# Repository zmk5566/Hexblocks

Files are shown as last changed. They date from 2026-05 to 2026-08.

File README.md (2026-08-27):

<h1 align="center">HexBlocks</h1>

<p align="center">
  <em>Open-Source Prototyping of Reconfigurable Physical Interfaces with Semantic Continuity</em>
</p>

<p align="center">
  <a href="https://zmk5566.github.io/Hexblocks/">Walkthrough</a>
</p>

<p align="center">
  HexBlocks modules arranged for a live prototype
</p>

HexBlocks is an open-source software-hardware framework for rapid, on-the-fly prototyping of reconfigurable physical interfaces. It combines magnetic sensor/actuator modules, a battery-powered hub, a browser authoring UI, and a live schema in one workspace.

The core design goal is semantic continuity: physical modules, authoring references, and runtime targets stay bound to stable UID-keyed entities as the assembly changes. The reference implementation supports hub-resident Event-Condition-Action execution for standalone prototypes and sensor-stream integration through a Python bridge for browser and OSC workflows.

## Interface

<p align="center">
  HexBlocks interface
</p>

## Links

- Video walkthrough: <https://zmk5566.github.io/Hexblocks/>
- Schematics: [`schematics/`](schematics/) (KiCad project `schematics.kicad_pro`)
- Enclosures: [`openscad-model/`](openscad-model/) (OpenSCAD sources + STL)
- Hardware sources: [`hardware/`](hardware/) (firmware + PCB)
- Firmware topology runtime: [`hardware/docs/topology-runtime.md`](hardware/docs/topology-runtime.md)

## Repo layout

```
hardware/             ESP32-C3 firmware (hub + 7 module types) and PCB
  firmware/hub/       six-face wired Hub — CAN master, BLE/USB, ECA
  firmware/wifi_hub/  same shared Hub core plus Wi-Fi/OSC fallback
  firmware/motor_hub/ one-face BLE/USB hub with a built-in dual-motor actuator
  firmware/module_*/  per-module sketches (imu, led, vibration, motor,
                      amplifier, light_resistor, resistor)
  firmware/lib/       shared C++ libraries: WearBlocksCAN, *Protocol,
                      *Descriptor, *Module, *ECA (bytecode interpreter),
                      *Transport policy and optional *Wireless runtime
  pcb/                board files
schematics/           KiCad project (board + schematic)
openscad-model/       hex enclosure SCAD sources + exported STL
frontend/
  bridge/             Python bridge runtime: serial_bridge.py (WS + HTTP),
                      OSC forwarding + correlated control ingress,
                      wb_protocol.py, wb_eca.py, transport.py (USB-CDC + BLE)
  js/                 ES modules: ws-client, eca-encoder/decoder,
                      llm-catalog, recommendation-plan, demo-programs
  js/components/      Lit UI: wb-app, wb-block-canvas, wb-sim-stage (Three.js), wb-llm-panel,
                      wb-sensor-panel, wb-eca-inspector, wb-status-bar,
                      wb-devices-panel, wb-debug-console
  tools/              frontend smoke/debug utilities
  index.html          static entry point, served by the bridge
```

## Quickstart - Simulator

Use simulator mode first if you do not have hardware attached.

1. **Install bridge dependencies.**

   ```bash
   cd frontend/bridge
   python -m venv .venv
   source .venv/bin/activate
   pip install -r requirements.txt
   ```

2. **Run the bridge simulator.**

   ```bash
   python serial_bridge.py --sim --sim-demo
   ```

3. **Open the UI.** Browse to `http://localhost:3000`.

The bridge serves the static frontend on port 3000 and broadcasts live events
on `ws://localhost:8765`. The simulator creates a demo topology for testing
Blockly upload, ECA execution, actuator state replay, and OSC forwarding
without flashing a hub.

Run the core bridge checks:

```bash
cd frontend/bridge
python serial_bridge.py --selftest
python -m pytest test_wb_eca.py test_osc_bridge.py test_llm_bridge.py
```

## Quickstart - Hardware Hub-Resident ECA

The hub evaluates rules locally. A companion computer is only needed to author or inspect the program.

1. **Flash the hub.** Connect the hub board over USB-C. The default
   `hardware/firmware/hub` target is the deterministic wired build: CAN module
   bus plus USB/BLE companion link, with no Wi-Fi SoftAP or OSC listener.
   Compile it for ESP32-C3 with `arduino-cli`:

   ```bash
   # Install the core once
   arduino-cli core install esp32:esp32

   # Compile and upload (replace /dev/cu.usbmodem* with your port)
   arduino-cli compile --fqbn esp32:esp32:esp32c3 \
     --libraries hardware/firmware/lib hardware/firmware/hub
   arduino-cli upload --fqbn esp32:esp32:esp32c3 \
     -p /dev/cu.usbmodem* hardware/firmware/hub
   ```

   To enable module-to-Hub Wi-Fi/OSC fallback, compile and upload
   `hardware/firmware/wifi_hub` instead. Both targets share the same Hub and
   registry implementation; `wifi_hub` only selects the wireless adapter.

   ```bash
   arduino-cli compile --fqbn esp32:esp32:esp32c3 \
     --libraries hardware/firmware/lib hardware/firmware/wifi_hub
   arduino-cli upload --fqbn esp32:esp32:esp32c3 \
     -p /dev/cu.usbmodem* hardware/firmware/wifi_hub
   ```

   For the standalone ESP32-C3FH4 + DRV8410 board, compile and upload
   `hardware/firmware/motor_hub` instead. It exposes the same BLE/USB hub
   protocol, uses GPIO5 as its single external Face 1, and advertises its
   onboard M1/M2 pair as `Built-in Dual Motor` without consuming a CAN slot.

2. **Flash each module.** Same flow, one sketch per module type. Example for the IMU module:

   ```bash
   arduino-cli compile --fqbn esp32:esp32:esp32c3 \
     --libraries hardware/firmware/lib hardware/firmware/module_imu
   arduino-cli upload --fqbn esp32:esp32:esp32c3 \
     -p /dev/cu.usbmodem* hardware/firmware/module_imu
   ```

   Repeat for `module_led`, `module_vibration`, `module_motor`, `module_amplifier`, `module_light_resistor`, `module_resistor`.

3. **Power up.** Snap modules onto the hub. The hub enumerates them over CAN, allocates slots, and (if a program is in NVS) starts evaluating immediately. No companion computer required.

4. **Author or replace the program (optional).** Run the bridge (see Mode B), open the browser UI, write rules in the Blockly canvas or via the LLM panel, and click upload. The encoded bytecode is sent as `$P <base64>` over the active transport, persisted in NVS, and runs on every boot until cleared with `$PC` (clear) or `$PE` (erase NVS).

### ECA v4 timing model

ECA timing is cooperative: the Hub never sleeps or busy-waits while a rule is delayed. `hold_ms` and `cooldown_ms` belong to the rule; each action independently has `delay_ms`, `duration_ms`, and one of three modes:

- `TRIGGER`: starts once per rule episode. A delayed trigger remains scheduled after a one-tick event is consumed.
- `WHILE_TRUE`: stays active only while the rule remains true.
- `STREAM`: refreshes live sensor/VC/variable parameters at `update_interval_ms` (minimum 20 ms).

Transient event channels such as shake, free-fall, and HR spike must use rule `hold_ms = 0`; use action `delay_ms` when the response should happen later.

LED, vibration, and audio outputs use ownership tokens so an older duration timer cannot stop a newer effect on the same module. Stop, clear, and program replacement emit a safe output-specific stop. The output modules also enforce duration locally; `STREAM` commands renew a short lease, so a lost Hub/CAN connection expires the output without waiting for a final STOP frame.

ECA v4 is a wire-format change. Reflash the Hub plus `module_led`, `module_vibration`, and `module_amplifier`, then upload the workspace again; the Hub intentionally uses a new `prog_v4` NVS key rather than interpreting stored v3 bytes.

## Quickstart - Sensor Stream + Browser

Same hardware setup as Mode A. The hub keeps any uploaded program running; the bridge subscribes to the same `$S/$D/$H/$T` stream and forwards it to the browser. Clearing the program (`$PC`) gives a pure stream-only configuration.

1. **Install the bridge dependencies.**

   ```bash
   cd frontend/bridge
   pip install -r requirements.txt   # websockets, pyserial, requests, bleak
   ```

2. **Run the bridge.** The bridge serves the static frontend on `http://localhost:3000` and pushes events on `ws://localhost:8765`.

   ```bash
   # USB-CDC (auto-detect or pass a port)
   python serial_bridge.py /dev/cu.usbmodem*

   # First run: start idle, then choose USB serial or BLE in the Connections panel.
   python serial_bridge.py --idle

   # BLE direct reconnect, after a device address is known:
   python serial_bridge.py --ble <BLE_ADDRESS>

   # No hardware? Headless simulator with three demo programs:
   python serial_bridge.py --sim --sim-demo
   ```

3. **Open the UI.** Browse to `http://localhost:3000`. Sparklines appear in `wb-sensor-panel`; raw bridge traffic in `wb-debug-console`; the program currently on the hub in `wb-eca-inspector`.

4. **Optional: LLM authoring.** Set `DEEPSEEK_API_KEY` in `frontend/bridge/.env` so the bridge's `/api/chat` proxy can reach the model. The chat panel translates utterances into `<workspace_update>` envelopes that the canvas validates against the live module schema before letting you accept.

5. **Optional: bidirectional OSC.** Open the OSC panel from the status bar,
   add a loopback forwarding target, and use auto-populate to seed one address
   per live sensor channel. The bridge also listens on `127.0.0.1:7001` for
   `/hex/control/<uid>/actuator` and replies with correlated
   `ack`/`nack`/`state` messages. Non-loopback OSC in either direction requires
   launching the bridge with `--osc-allow-remote`.

## Build Instructions

### Firmware

No `platformio.ini` is committed — the canonical build path is `arduino-cli` against the per-sketch directories under `hardware/firmware/`. Shared libraries live in `hardware/firmware/lib/` and must be passed via `--libraries` (see commands above). Target board: `esp32:esp32:esp32c3` (ESP32-C3-MINI-1). The hub additionally requires NimBLE-Arduino; install it once with `arduino-cli lib install "NimBLE-Arduino"`.

PlatformIO users can build the same sketches by adding each `module_*`, `hub`,
`wifi_hub`, and `motor_hub` directory as a PlatformIO environment with
`framework = arduino` and `board = esp32-c3-devkitm-1`; no project file is
provided.

### Bridge

```bash
cd frontend/bridge
python -m venv .venv && source .venv/bin/activate
pip install -r requirements.txt
python serial_bridge.py --selftest    # parser + ECA round-trip checks
```

Tested with CPython 3.11. No `pyproject.toml`; the bridge is a small set of scripts driven by `requirements.txt`.

### Frontend

The frontend is plain ES modules. There is no bundler and no build step.
`serial_bridge.py` serves `frontend/index.html` and `frontend/js/` directly
over HTTP on port 3000. Open `http://localhost:3000` in a Chromium-based
browser. The Connections panel is mediated by the Python bridge, so USB serial
selection and BLE pairing also work in Firefox.

## License

- Code: MIT. See [`LICENSE`](LICENSE).
- Hardware design files and enclosure models: CC BY 4.0. See
  [`LICENSE-hardware`](LICENSE-hardware).

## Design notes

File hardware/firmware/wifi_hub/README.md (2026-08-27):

# WearBlocks Wi-Fi Hub

This is the six-face Hub build with the optional Wi-Fi/OSC module transport.
It shares the complete runtime and `ModuleRegistry` implementation with
`../hub`; this directory only selects the wireless adapter at compile time.

Choose one six-face Hub target:

| Target | Runtime links | Wi-Fi SoftAP / OSC |
|---|---|---|
| `hardware/firmware/hub` | CAN + USB/BLE | No |
| `hardware/firmware/wifi_hub` | CAN + USB/BLE + Wi-Fi | Yes |

Compile this variant with:

```bash
arduino-cli compile --fqbn esp32:esp32:esp32c3 \
  --libraries hardware/firmware/lib hardware/firmware/wifi_hub
```

The Wi-Fi Hub provisions supported modules over CAN, runs a WPA2 SoftAP, and
accepts UID-keyed OSC-over-UDP samples. ECA execution remains on the Hub. See
[`hardware/docs/wifi-osc-fallback.md`](../../docs/wifi-osc-fallback.md) for the
transport modes and wire protocol.

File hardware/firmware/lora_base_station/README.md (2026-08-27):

# WearBlocks LoRa Base Station

Firmware target: ESP32-S3 + SX1262.

Install Arduino libraries before compiling:

- RadioLib
- ArduinoJson

Edit these constants at the top of `lora_base_station.ino` before flashing:

- `WIFI_SSID`
- `WIFI_PASS`
- `HTTP_ENDPOINT`
- `HTTP_BEARER_TOKEN`
- SX1262 pins
- LoRa frequency/power parameters

Runtime behavior:

- Receives `WBLR` batch frames from LoRa logger modules.
- Uploads each new batch with `HTTP POST`.
- Sends a LoRa ACK only after the HTTP API returns 2xx.
- Re-ACKs duplicate `(node_uid, boot_id, sequence)` batches from a short RAM cache.

RF defaults are CN470-like placeholders. Confirm the final frequency, power,
antenna, duty-cycle assumptions, and SRRC requirements before field use.

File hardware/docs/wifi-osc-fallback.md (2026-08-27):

# Wi-Fi / OSC Fallback Runtime

Status: end-to-end sensor, actuator, topic, ACK/retry, and duplicate-suppression
runtime for the explicit `wifi_hub` variant.

This runtime belongs to the explicit `hardware/firmware/wifi_hub` build. The
default `hardware/firmware/hub` build shares the same CAN/BLE/USB/ECA core but
does not include Wi-Fi, create a SoftAP, or listen for OSC/UDP packets.

```bash
arduino-cli compile --fqbn esp32:esp32:esp32c3 \
  --libraries hardware/firmware/lib hardware/firmware/wifi_hub
```

The reference system still treats CAN as the deterministic local module bus,
but each module can carry a transport policy. The hub can run a WPA2 SoftAP and
accept OSC-over-UDP packets from Wi-Fi modules. ECA execution remains on the
hub; CAN and Wi-Fi sensor samples update the same UID-keyed ECA cache.

## Transport modes

Configured per module:

| Mode | Behavior |
|---|---|
| `can_only` | Use CAN only. Ignore Wi-Fi sensor samples. |
| `wifi_only` | Use Wi-Fi for runtime data even if CAN is physically present. |
| `can_primary_wifi_fallback` | Default. Use CAN while healthy; switch to Wi-Fi after CAN detach/fail. |
| `wifi_primary_can_fallback` | Prefer Wi-Fi when the endpoint is known; use CAN if Wi-Fi is unavailable. |
| `dual_send_debug` | Send actuator/topic commands over both links and accept both sensor paths for debugging. |

Hub commands:

```text
$W,INFO
$W,CONFIG ALL <mode>
$W,CONFIG <uidHex> <mode>
```

`$W,INFO` emits the SoftAP SSID, AP IP, UDP port, AP password, and pairing
token. The first module provisioning and recovery path is still CAN: attach the
module, use the hub command path to set the module configuration, then let the
module persist it in NVS.

## CAN provisioning

Wi-Fi profile data is sent over CAN with a dedicated system config path, not
the actuator config path:

```text
WB_MSG_SYS_CONFIG      0x090
WB_MSG_SYS_CONFIG_ACK  0x091
```

The hub sends a chunked binary profile to the assigned module slot after ACK
and whenever `$W,CONFIG` changes a module's transport mode. The profile
contains `hubId`, `ssid`, `pass`, `token`, `udpPort`, `transportMode`, an
enabled flag, and a FNV32 checksum. Modules save the profile in NVS and can
reconnect to the same hub SoftAP without CAN on later boots.

The hub SoftAP SSID is unique by default:

```text
HEX-<hubShortId>
```

The AP password and OSC token are generated once and persisted in hub NVS.

## Hub wire output

The hub adds link-state lines to the existing `$` protocol:

```text
$W,<uid>,<activeLink>,<transportMode>,<topologyState>,<ip>,<port>
$WIFI,AP,<ssid>,<ip>,<port>
$WIFI,PASS,<password>
$WIFI,TOKEN,<token>
```

Wireless-only modules use `REMOTE,0` as their parent label in `$H` and `$T`
rows. The bridge maps that to `parent_remote=true` and the UI renders the module
as remote/unplaced rather than attached to a hub face.

## OSC messages

All OSC messages use typed arguments. Runtime samples are latest-value wins;
configuration and actions carry IDs so the receiver can ACK, NACK, retry, and
deduplicate.

Module to hub:

```text
/wb/module/hello       s i s i s   uid, fwHash, transportMode, seq, token
/wb/module/heartbeat   s i s s     uid, seq, linkState, token
/wb/sensor             s i f i s   uid, channel, value, seq, token
/wb/descriptor/blob    s i i b s   uid, fwHash, seq, serializedDescriptor, token
/wb/ack                s i s       uid, msgId, status
/wb/nack               s i s       uid, msgId, reason
```

Hub to module:

```text
/wb/descriptor/request s i i s     uid, fwHash, msgId, token
/wb/action             s i i i b s uid, cmd, msgId, paramLen, params, token
/wb/topic              s i i i s   uid, channel, enable, msgId, token
```

Broadcast is intentionally reserved for discovery and low-frequency status.
Runtime sensor and actuator/control messages should be unicast between a module
and the hub.

For actions and topic changes, the Hub keeps a fixed pending table and retries
after 250 ms, up to three sends. Modules remember the most recent action and
topic message IDs: a retry is ACKed again but its callback is not executed a
second time. ECA `STREAM` action updates and repeated desired topic state are
coalesced while an ACK is outstanding, preventing a slow Wi-Fi link from
turning into an unbounded queue.

The companion-visible correlated wire lines are:

```text
$AO <requestId> <uid> <cmd> [wire params...]       host control request
$AS,<uid>,<cmd>,<paramLen>,<hex>[,<requestId>]     routed state echo
$WA,<uid>,<msgId>,<detail>[,<requestId>]           module ACK
$WN,<uid>,<msgId>,<reason>[,<requestId>]           module NACK/timeout
```

The standard wired Hub understands `$AO` and emits `$AS` too, but never starts
Wi-Fi. This keeps `hub` deterministic while `wifi_hub` owns the wireless
fallback policy.

## Module coverage

- `module_resistor`, `module_light_resistor`, and `module_imu` route sensor
  samples through `WBWirelessModule`.
- `module_led`, `module_vibration`, `module_amplifier`, and `module_motor`
  receive Wi-Fi actuator commands through the same wrapper.
- CAN remains active according to each module's transport policy; the wrapper
  does not fork the application-level actuator implementation.

## Current limitations

- Descriptor transfer is implemented as a single OSC blob. If descriptor or
  config payloads grow beyond one safe UDP datagram, promote this to chunked
  `seq/index/total/crc` transfer.
- ESP32-C3 can run CAN, Wi-Fi, and BLE, but Wi-Fi and BLE share the 2.4 GHz RF.
  During Wi-Fi fallback, BLE should stay on low-frequency status/config traffic.

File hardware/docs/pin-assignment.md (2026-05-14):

# WearBlocks Pin Assignment

> **2026-04 update — digital-presence PosID**
> Hub is now **ESP32-C3-MINI-1** (not S3). PosID uses **digital presence**
> (internal pull-up on hub + POS_ID tied to GND on module's docking face),
> not ADC + resistor network. See `posid-topology.md` for historical notes
> and the current scheme.

## Hub: ESP32-C3-MINI-1

| GPIO | Function | Notes |
|---|---|---|
| GPIO6 | TWAI_TX (CAN TX) | To SN65HVD230 TXD. Repurposes JTAG MTCK. |
| GPIO7 | TWAI_RX (CAN RX) | From SN65HVD230 RXD. Repurposes JTAG MTDO. |
| GPIO0 | Face 1 presence | digital INPUT_PULLUP. **Boot strap — caution**: module must not short this to GND at power-up. |
| GPIO2 | Face 2 presence | digital INPUT_PULLUP. **Boot strap — caution** as above. |
| GPIO3 | Face 3 presence | digital INPUT_PULLUP. Clean ADC1_CH3 line per user test. |
| GPIO4 | Face 4 presence | digital INPUT_PULLUP. Clean. |
| GPIO8 | Face 5 presence | digital INPUT_PULLUP. **Boot strap — caution.** Sometimes wired to onboard LED on dev boards — test first. |
| GPIO10 | Face 6 presence | digital INPUT_PULLUP. |
| GPIO9 | Status LED (optional) | Boot button on most dev boards; OK to drive as output after boot. |
| GPIO18 | USB D- | USB-OTG if using native USB as serial |
| GPIO19 | USB D+ | |
| GPIO20/21 | UART0 RX/TX | For flashing + serial console via USB-UART |

**ADC note**: ESP32-C3 only has 5 usable ADC1 pins (GPIO 0–4) and ADC2 (GPIO 5) is unsupported by the Arduino-ESP32 core. For the face count to reach 6 on C3, we switched PosID from analog to digital; this also sidesteps dev-board ADC pin contamination and calibration.

**Strap pin caveat**: GPIO 0/2/8/9 are boot-mode strapping pins. A module plugged into its corresponding face at power-up will short the strap pin to GND, which can force the MCU into download mode. Boot procedure in firmware:
- Power hub on with all faces empty, wait for `[WAIT] Listening for module HELLO`
- Then plug modules in

Once the bootloader has handed off, these pins are free to read LOW. A future PCB respin should avoid strap pins for face presence; for breadboard prototypes the workaround above is acceptable.

## Module: ESP32-C3-MINI-1

| GPIO | Function | Notes |
|---|---|---|
| GPIO0 | TWAI_TX (CAN TX) | To SN65HVD230 TXD. Strap pin — must not boot low; default TWAI idles high. |
| GPIO1 | TWAI_RX (CAN RX) | From SN65HVD230 RXD |
| GPIO3 | I2C SDA | For MPU6050, MAX30102, BME280 |
| GPIO4 | I2C SCL | |
| GPIO2 | Child-presence face A (down-half stack detect) | INPUT_PULLUP. Strap pin caveat applies when a child module is stacked at boot. |
| GPIO5 | Child-presence face B (down-half stack detect) | INPUT_PULLUP. ADC2 unreliable but digital is fine. |
| GPIO10 | Child-presence face C (down-half stack detect) | INPUT_PULLUP. |
| GPIO8 | Status LED | Module state indicator |
| GPIO9 | Boot button / reserved | |

**PosID behaviour**:
- Module's docking face has its POS_ID pin **hard-tied to GND on the PCB** (or equivalently to POS_GND pin of the connector — they're both ground).
- Module does not need to read its own POS_ID; `MY_FACE` is a compile-time constant baked in firmware per PCB variant.
- Module's three "down-half" faces have POS_ID routed to INPUT_PULLUP GPIOs (above), so the module detects when someone stacks onto it, and broadcasts `WB_MSG_CHILD_EVENT` on CAN.

## SN65HVD230 CAN Transceiver Wiring

| Pin | Connection |
|-----|---|
| TXD | ESP32 TWAI_TX GPIO |
| RXD | ESP32 TWAI_RX GPIO |
| CANH | Bus CAN-H (to pogo pin) |
| CANL | Bus CAN-L (to pogo pin) |
| VCC | 3.3V |
| GND | GND |
| Rs | GND (slope control = high speed) |
| Vref | NC (unused) |

**Bus termination:** 120Ω between CAN-H and CAN-L on the hub only.

## 6-Pin Hex Face Connector (unchanged physically; POS_ID role changed)

| Pin # | Signal | Direction | Notes |
|---|---|---|---|
| 1 | CAN-H | Bidirectional | Shared bus |
| 2 | CAN-L | Bidirectional | Shared bus |
| 3 | VCC | Power out (hub / host module) | 3.3V |
| 4 | GND | Common ground | |
| 5 | POS_ID | **Digital low = dock present** | On child side: tied to GND. On host side: GPIO with internal pull-up. |
| 6 | POS_GND | GND reference | Dedicated ground alongside POS_ID for clean digital reference |

## PosID detection logic

```
Host side (hub or parent module):
    pinMode(FACE_PIN_N, INPUT_PULLUP);
    bool occupied = (digitalRead(FACE_PIN_N) == LOW);

Child side (docking face):
    POS_ID pin on the PCB is a solder trace to GND. No MCU code involved.

Identity:
    Module sends CAN HELLO with MY_FACE (compile-time constant encoded in firmware).
    Host cross-checks: "I saw my face N just become occupied AND this HELLO just arrived → they correlate."

Stack:
    Each host module has 3 child-presence GPIOs (down-half faces only).
    When any goes LOW, module sends WB_MSG_CHILD_EVENT_BASE+mySlot on CAN.
    Hub consumes these events to maintain the parent-child tree.
```

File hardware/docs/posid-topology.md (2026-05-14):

# PosID Wiring — Topology B (Symmetric)

This is the canonical wiring spec for the 6-face PosID circuit on every WearBlocks hex (hub or module).  
It's the **only** topology (out of the three we considered) that supports **both** connection modes:

- **A. Hub ↔ Module** — module plugs into any of the hub's 6 faces.
- **B. Module ↔ Module stack** — one module's face docks to another module's face.

Rationale: since a module can play either role (host or guest in a stack), every face on every hex needs to be electrically self-sufficient. If one side relies on the neighbor to provide the pull-up (or pull-down), the circuit collapses whenever that neighbor happens not to have it — exactly what breaks module-on-module stacking.

## Per-face schematic

Every hex face (on hub **and** on every module) is wired identically:

```
                VCC  (3.3V rail)
                 │
                 │
                ┌┴┐
                │ │   R_face_N     ← unique per face position N = 1..6
                │ │   (1k / 2.2k / 3.3k / 4.7k / 6.8k / 10k)
                └┬┘
                 │
                 ├─────o POS_ID   ─── pogo pin ───►  to neighbor's POS_ID
                 │
                 ├─────o ADC_N    (only connected on sides that read this face;
                 │                 hub reads all 6; proto-module reads its 1 active face)
                 │
                ┌┴┐
                │ │   10 kΩ       (pull-down, same value on every face)
                │ │
                └┬┘
                 │
                 │
                GND
                 │
                 └─────o POS_GND  ─── pogo pin ───►  common ground reference
```

Per face you need **exactly 2 resistors**:
- `R_face_N` (pull-up to VCC) — identifies the face position
- `10 kΩ` (pull-down to GND) — shared reference

## R_face values by position

| Face N | R_face_N | V_idle (no neighbor docked) | ADC_idle (12-bit, 3.3V ref) |
|---|---|---|---|
| 1 | 1.0 kΩ | **3.00 V** | ~3720 |
| 2 | 2.2 kΩ | **2.70 V** | ~3350 |
| 3 | 3.3 kΩ | **2.48 V** | ~3080 |
| 4 | 4.7 kΩ | **2.24 V** | ~2780 |
| 5 | 6.8 kΩ | **1.96 V** | ~2440 |
| 6 | 10 kΩ | **1.65 V** | ~2050 |

`V_idle(N) = 3.3 × 10k / (R_face_N + 10k)`

## Docked state — two faces connected through pogo

When face P (on side A) docks with face Q (on side B), the POS_ID lines merge. The combined network has:

- Two pull-ups in parallel: `R_eq = R_P × R_Q / (R_P + R_Q)`
- Two pull-downs in parallel: `5 kΩ` (10k ∥ 10k)

Resulting voltage on the shared POS_ID line:

```
V_docked(P, Q) = 3.3 × 5k / (R_eq + 5k)
```

Both sides' ADCs (if connected) see the **same** voltage. Each side knows its own R value and the universal pull-down scheme, so each side can in principle solve for the neighbor's R (and therefore its face index).

### Voltage table, V_docked(P, Q)

Rows = P (this side), columns = Q (neighbor). Diagonal highlighted because it collides with V_idle(P).

| P\Q | 1 (1k) | 2 (2.2k) | 3 (3.3k) | 4 (4.7k) | 5 (6.8k) | 6 (10k) | V_idle(P) |
|---|---|---|---|---|---|---|---|
| **1** | **3.00** | 2.90 | 2.86 | 2.83 | 2.81 | 2.79 | 3.00 |
| **2** | 2.90 | **2.70** | 2.61 | 2.54 | 2.48 | 2.43 | 2.70 |
| **3** | 2.86 | 2.61 | **2.48** | 2.38 | 2.28 | 2.21 | 2.48 |
| **4** | 2.83 | 2.54 | 2.38 | **2.24** | 2.12 | 2.01 | 2.24 |
| **5** | 2.81 | 2.48 | 2.28 | 2.12 | **1.96** | 1.82 | 1.96 |
| **6** | 2.79 | 2.43 | 2.21 | 2.01 | 1.82 | **1.65** | 1.65 |

### Two observations

1. **Diagonal collision**: `V_docked(N, N) = V_idle(N)` for every N. Symmetric face-to-same-face dock looks identical to "not docked at all." This is a fundamental consequence of the symmetric divider and cannot be avoided with this resistor scheme alone. For the current prototype where each module has only **one active face** of a **fixed index**, this only matters if you try to stack two modules whose active faces happen to be the same index — avoid that by assigning different face indices to different module types (e.g., IMU=face 1, LED=face 2, etc.).

2. **Row 1 is compressed**: when R_P = 1k (face 1), all V_docked values fall in a 0.21 V band (2.79–3.00 V). The small pull-up dominates and swamps the neighbor's signal. Face 1 can tell "docked or not" but cannot reliably identify which face it's docked to, unless the ADC is very clean. Rows with larger R_P spread out more (row 6 spans 1.14 V).

## Detection rules for firmware

### Occupancy (`isFaceOccupied` replacement)

The current `adc > 200` rule assumes pull-down-only-when-empty, which is topology C and is wrong for topology B. Correct rule:

> Face N is occupied iff `|V_measured − V_idle(N)|` > `V_TOL`.

With `V_TOL ≈ 0.10 V` (about 125 ADC counts), the diagonal-collision edge cases are misdetected as "empty", but all other dock combinations are cleanly detected. Good enough for the hub↔module case where the hub has 6 different faces and the module tag maps to a single R.

### Face identification of neighbor

Given a measurement V on this-side face P, solve for R_Q:

```
R_eq = 5k × V / (3.3 − V) × (1/5k - 1/R_eq) ...  // closed form below
```

Closed form: let `x = V / 3.3`, then `R_eq = 5 × x / (1 − x)` (kΩ), and
`R_Q = R_P × R_eq / (R_P − R_eq)`.

Match R_Q to the nearest value in {1.0, 2.2, 3.3, 4.7, 6.8, 10} kΩ within 20 % tolerance. If no match, treat as "unknown face / no dock."

This decode works well for P = 4, 5, 6 (large R_P); may be ambiguous for P = 1, 2. For the prototype, the hub has 6 different R_P, so at least 4 of them decode reliably — good enough to cover most plug positions.

## Wiring checklist

Per hex PCB (whether hub or module):

- [ ] **6 × face-specific pull-ups** to VCC, values {1.0k, 2.2k, 3.3k, 4.7k, 6.8k, 10k}, one per face position.
- [ ] **6 × 10kΩ pull-downs** to GND, one per face position.
- [ ] All 6 POS_ID lines routed to their respective pogo pin (pin 5 of the 6-pin face connector).
- [ ] POS_GND (pin 6) tied to GND — dedicated return so face-to-face current doesn't share the digital GND plane.
- [ ] On the **hub**: all 6 POS_ID lines also tap the MCU's 6 ADC pins (GPIO {1, 2, 3, 6, 7, 8}).
- [ ] On a **prototype module** (single active face): POS_ID of the active face taps the MCU's single ADC pin (GPIO 2 on ESP32-C3); the other 5 faces only need the R_face + 10k + POS_ID wiring for the stack case — they don't need ADC taps unless you want the module to be able to host another module on those faces.

Sanity reading with a multimeter **before flashing**:

With the board powered (3.3V rail up) and nothing docked into any face, measure each POS_ID pin to GND. You should see six distinct voltages matching the `V_idle` column above, within ~5 %. If any pin reads 0 V → pull-up missing or shorted. If any reads VCC → pull-down missing.

## Code impact summary

Files to update once you've confirmed topology B on the actual board:

| File | Change |
|---|---|
| `hardware/firmware/lib/WearBlocksPosID/WearBlocksPosID.cpp` | Rewrite `isFaceOccupied` to compare against `V_idle(N)` table with a tolerance; optionally add `decodeNeighborFace(uint8_t myFace)` that returns the neighbor's face index via the closed-form decode above. |
| `hardware/docs/pin-assignment.md` | Replace the "POS_ID Resistor Values" section with a cross-reference to this doc (and keep only the R_face_N list there). |

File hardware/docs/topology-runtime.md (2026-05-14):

# Firmware Topology Runtime

Status: current firmware behavior as of 2026-05-08.

This note documents the hub/module topology rules implemented in firmware.

## Identity Model

- `uid` is the stable external identity for a physical module.
- `slot` is a hub-local CAN address alias. It can change across hub resets and
  should not be used as durable identity outside the hub firmware.
- `fwHash` is a descriptor cache key. When a known UID sends HELLO with the same
  `fwHash`, the hub can ACK it as cached. When the hash changes, the hub keeps
  the module registered but requests a fresh descriptor.

## Registry Invariants

The hub keeps these invariants after attach, detach, rebind, and reap:

- One `(parentSlot, parentFace)` has at most one logical occupant.
- Removing a parent removes the whole subtree, leaf first.
- Detaching a parent detaches the whole subtree, leaf first.
- Replacing a stale `DETACHED` occupant emits `$U,<oldUid>` before accepting the
  new UID on that face.
- `$Q,STATUS` and `$Q,TOPO` surface `REGISTERED` and `PENDING` modules, but skip
  `DETACHED` modules so a browser resync does not revive a module during the
  detach TTL.

## HELLO Matching

The hub always looks up UID before consuming an attach candidate.

- Known `REGISTERED` UID: treat HELLO as keepalive / duplicate. Re-ACK only and
  never consume an attach event.
- Known `PENDING` UID: re-ACK and re-request descriptor. The existing binding is
  preserved.
- Known `DETACHED` UID: consume a bindable attach candidate, rebind if needed,
  reattach, and emit `$H` or `$F`.
- Unknown UID: first try topology memory, then fall back to the bindable attach
  queue. If more than one attach candidate is active, the hub still binds but
  logs `[ATT] ambiguous HELLO ...` because FIFO cannot prove physical identity.

## Topology Memory

The hub stores remembered bindings in NVS as:

```text
uid -> parentUid, parentFace
```

`parentUid == 0` means the parent is the hub. Memory is updated when a module
registers or reattaches, and flushed to NVS at most once every 30 seconds.

Topology memory is used mainly for hub-only reboot recovery. If modules remain
powered while the hub reboots, multiple occupied faces may appear at the same
time. FIFO attach order cannot reliably map those HELLOs back to faces, so the
hub trusts a remembered binding when:

- the parent is available,
- the remembered hub face is physically occupied, and
- the remembered face is not held by another live module.

If a remembered face is busy with another live UID, the entry is treated as
stale, forgotten, and the HELLO falls back to the attach queue.

## Manual Forget Command

Use these commands before an offline physical rearrange:

```text
$Q,FORGET ALL
$Q,FORGET <uidHex>
```

`$Q,FORGET ALL` clears in-RAM topology memory and removes the NVS blob. If NVS
erase fails, the hub reports `nvs=deferred` and retries by flushing an all-zero
table later.

`$Q,FORGET <uidHex>` removes one remembered binding and flushes immediately when
possible.

## Recovery Loops

- Modules send fast HELLO retries before ACK and a low-frequency keepalive HELLO
  after registration.
- The hub periodically re-enqueues occupied hub faces that do not currently hold
  a `REGISTERED` module. This lets hub reboot recovery and PENDING timeout
  recovery work without physically unplugging and replugging a module.
- PENDING modules retry descriptor requests. After the retry cap, the hub emits
  `$U,<uid>` and removes the slot, but preserves topology memory because a
  descriptor timeout does not prove the physical module is gone.
- Sensor data is forwarded only from `REGISTERED` modules. `PENDING` and
  `DETACHED` slots are ignored.

## Known Limitation

Without an external information source, firmware cannot perfectly identify
simultaneous physical rearranges. The current system has no per-face electrical
identity, per-port challenge, or user confirmation step.

Examples that remain ambiguous:

- two unknown modules are inserted at nearly the same time,
- two `DETACHED` known modules are reseated at nearly the same time,
- modules are rearranged while the hub is off and topology memory was not
  cleared first.

For reliable behavior during rearrangement, insert/reseat one module at a time
or run `$Q,FORGET ALL` before powering down and changing the layout.

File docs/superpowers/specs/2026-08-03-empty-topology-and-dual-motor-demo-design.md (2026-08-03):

# Empty Topology and Dual Motor Demo Design

## Goal

Make the frontend distinguish an available Hub from an empty bridge connection, and add a Blockly example that demonstrates independent control of the two motor channels.

## Hub Presence

The browser's WebSocket connection only means that the frontend can reach the Python bridge. It does not prove that a physical Hub exists. The topology therefore considers a Hub present when either:

- the bridge reports an active USB or BLE transport; or
- at least one module is visible, as happens after a simulator preset attaches its modules.

When neither condition is true, the palette does not render a Hub row and the topology canvas does not render the Hub, face edges, or face ghosts. Both areas show a short connection prompt instead. A connected physical Hub remains visible even when it has no attached modules.

## Dual Motor Blockly Example

The status bar gains `D4 Dual Motor Test` beside the existing Night Light, Theremin, and Motion Alert examples. In simulator mode, D4 clears the topology and attaches a built-in `motor_hub` actuator. After module discovery settles, the frontend loads one Blockly rule containing two chained motor actions:

1. M1 forward, speed 160, duration 2000 ms.
2. M2 reverse, speed 120, duration 3000 ms.

The two actions target the same discovered dual-motor actuator but preserve separate motor number, direction, speed, and duration fields. The demo state is rebound to the first active motor-capable module at load time, so the visible dropdown contains the live UID for either a motor-hub's built-in actuator or an external motor module. If no motor is present, the saved placeholder remains visible and upload validation reports the unresolved target.

## Scope

This change only affects initial Hub visibility and the demonstration preset. It does not add encoder feedback, vehicle-level movement blocks, acceleration ramps, braking modes, or nFAULT handling.

## Verification

- A pure frontend test covers Hub-presence decisions for disconnected, transport-connected, and simulator-module states.
- A JavaScript demo test verifies the two motor blocks, their independent fields, and live-UID rebinding.
- A Python simulator test verifies that D4 clears the old topology and attaches the built-in motor actuator.
- Existing frontend protocol tests and bridge tests remain green.

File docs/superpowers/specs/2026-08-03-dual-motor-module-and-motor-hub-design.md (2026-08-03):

# Dual Motor Module and Motor Hub Design

## Goal

Support the same independently controlled two-motor actuator in two hardware forms:

1. An external CAN actuator module that connects to any WearBlocks hub.
2. A standalone motor-hub that provides the normal hub runtime and drives its two onboard motors locally.

The existing non-motor hub remains a separate firmware target and does not acquire onboard motor hardware behavior.

## Hardware Roles

### Standard Hub

`hardware/firmware/hub/` remains the six-face WearBlocks hub. It provides USB, BLE, CAN module enumeration, topology management, ECA execution, and NVS persistence. It has no onboard motor actuator.

### External Motor Module

`hardware/firmware/module_motor/` remains a normal CAN actuator module. It registers with a hub, publishes a `dual_motor` actuator descriptor, receives `MOTOR_SET` over CAN, and controls its own M1 and M2 outputs independently.

### Motor Hub

`hardware/firmware/motor_hub/` is a separate firmware target for the ESP32-C3FH4 + DRV8410 motor board. It provides:

- direct USB serial and BLE Nordic UART Service connectivity;
- Blockly bytecode upload and ECA execution;
- NVS program persistence;
- CAN enumeration and control of external WearBlocks modules;
- one external module face, detected on GPIO5 and represented as Hub Face 1;
- a built-in dual-motor actuator executed locally.

The motor-hub pin assignments are:

| Function | GPIO |
|---|---:|
| Motor 1 IN1 / IN2 | 0 / 1 |
| Motor 2 IN1 / IN2 | 3 / 4 |
| External Face 1 presence | 5 |
| CAN RX / TX | 6 / 7 |
| DRV8410 nSLEEP | 10 |

`nFAULT` is outside this initial protocol test scope.

## Frontend Model

Both motor forms expose the same `dual_motor` actuator capability and use the same Blockly block. The module dropdown distinguishes targets by stable UID and display name:

- `Built-in Dual Motor` for the motor-hub's local actuator;
- `Dual DC Motor` for each external motor module.

The built-in actuator is advertised as a local device associated with the motor-hub. It does not consume Face 1 or a CAN module slot. Face 1 remains available for a physical external module.

A motor-hub may therefore control its two onboard motors and one or more external motor modules from the same Blockly workspace.

## Control Protocol

Both forms use action command `MOTOR_SET = 64` with four ECA parameters:

| Parameter | Values |
|---|---|
| motor | `1` or `2` |
| mode | `0` stop, `1` forward, `2` reverse |
| speed | `0..255` PWM duty |
| duration_ms | `0..65535`; `0` means continuous |

The packed actuator payload is:

```text
[motor, mode, speed, duration_hi, duration_lo]
```

M1 and M2 maintain separate mode, speed, and expiry state. Expiration of one motor must not modify the other motor.

## Action Routing

The shared ECA layer continues to encode `MOTOR_SET` consistently. The motor-hub adds a local actuator dispatch path:

1. Resolve the action target UID.
2. If it is the built-in motor UID, execute the packed command through the local DRV8410 driver.
3. Otherwise resolve the target to a registered CAN slot and send the normal actuator frame.

The standard hub does not register a local motor handler, so all module actuator actions retain their existing CAN behavior. The external motor module continues to receive the same five-byte payload through `WearBlocksProtocol`.

Direct `$A` commands follow the same routing rule as ECA actions.

## Bluetooth and USB Data Flow

The motor-hub uses the same Nordic UART Service UUIDs and line protocol as the standard hub. The frontend bridge can therefore connect through BLE or USB without a motor-specific transport mode.

```text
Blockly -> ECA bytecode -> BLE or USB -> motor-hub
                                      |-> local DRV8410 M1/M2
                                      `-> CAN external modules
```

The motor-hub emits its built-in motor identity and descriptor during status synchronization so the existing capability-based Blockly dropdown can discover it.

## Safety and Runtime Behavior

- Boot starts with `nSLEEP` low and all PWM outputs at zero.
- `nSLEEP` goes high only after PWM initialization succeeds.
- Invalid motor numbers or modes are ignored.
- A stop command or speed zero clears that motor's timer and drives both corresponding inputs low.
- Duration expiry is non-blocking and independently checked for each motor.
- Motor control never delays CAN processing, BLE handling, ECA evaluation, or face detection.

## Testing

The implementation must verify:

- JavaScript encode/decode round-trip preserves motor, mode, speed, and duration;
- capability mapping recognizes built-in and external motor descriptors;
- simulator independently controls and expires M1 and M2;
- standard hub behavior remains unchanged when no local motor handler is installed;
- local motor targets do not emit CAN actuator frames;
- external motor targets from a motor-hub do emit CAN actuator frames;
- the standard hub, external motor module, and motor-hub firmware targets all compile for ESP32-C3;
- physical bring-up verifies BLE connection, Blockly upload, local M1/M2 operation, and an external module on GPIO5 Face 1.

## Scope

This phase implements direction, speed, stop/start, and optional duration only. Encoder feedback, nFAULT handling, braking modes, acceleration ramps, closed-loop speed control, and higher-level vehicle movement blocks remain outside scope.

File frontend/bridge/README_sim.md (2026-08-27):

# Simulator ECA Validation Guide

End-to-end validation of the WearBlocks ECA pipeline **without physical
hardware**, using the built-in Python ECA engine (`wb_eca.py`) inside the
simulator.

## Architecture

```
┌──────────────┐      WS       ┌──────────────────┐       ┌────────────┐
│  Blockly UI  │ ──$P/$PR/$A─▶ │ serial_bridge.py │──────▶│ wb_eca.py  │
│ (wb-block-   │               │  (--sim modes)   │       │  engine    │
│   canvas)    │◀── actuator ──│                  │◀──────│            │
└──────────────┘    _state     └──────────────────┘       └────────────┘
          OSC control :7001 ──────────▶│
          ◀──── ack/nack/state ────────┘
                                      │
                         SimModule actuator state
                                      │
                                      ▼
                       sensor panel + Three.js twin
```

The Python engine is a 1:1 port of
`hardware/firmware/lib/WearBlocksECA/WearBlocksECA.cpp`, so bytecode that
works in sim should also work on hardware (and vice versa — divergences
are bugs in one engine or the other).

## Quick start

```bash
cd frontend/bridge
python serial_bridge.py --sim-demo
```

This auto-loads the 5-module demo (IMU + HR stacked on IMU F4 + Temp + LED + Vib)
and starts the WebSocket bridge on `:8765` plus HTTP on `:3000`.

Open `http://localhost:3000` in the browser.

Click **3D Twin** in the status bar to open the live Three.js view. It uses the
same UID-keyed topology and sensor/actuator caches as the 2D canvas, so a
physical Hub, the simulator, WebSocket controls, and OSC controls all update
one model.

## Unit tests

```bash
cd frontend/bridge
python -m pytest test_wb_eca.py -v
```

13 tests cover: bytecode parsing, magic/checksum rejection, condition
evaluation (GT/LT/AND/OR), `hold_ms`, `cooldown_ms`, `VAR_INC`,
virtual channels, topic extraction, run/stop/clear lifecycle.

## Golden end-to-end test

**Rule**: `IF imu.ax > 0.5 THEN LED[slot=5] SOLID red (cooldown 2000ms)`

### Steps

1. **Launch sim**

   ```bash
   python serial_bridge.py --sim-demo
   ```

   Expect:
   ```
   [bridge] HTTP serving ... on :3000
   [bridge] WebSocket on :8765
     [sim] demo: 5 CAN modules + 2 remote Wi-Fi modules, light stacked on IMU F4
   ```

2. **Open the UI**: `http://localhost:3000`. You should see 5 CAN modules,
   2 remote Wi-Fi modules, light stacked on IMU's F4, and an LED module on
   one of the hub faces.
   The right pane is the **ECA Rules** Blockly workspace (default 320 px
   wide — drag the `⸽` divider on its left edge to widen).

3. **Build the rule** (two paths — pick whichever is less friction):

   **Path A — Blockly drag-and-drop**

   - Open the toolbox categories on the left edge of the ECA Rules pane.
     Blockly boots from the unpkg CDN; if the categories do not appear,
     check DevTools for a `blockly_compressed.js` 404.
   - From **Rules**: drag out the `IF … THEN` block onto the workspace.
   - From **Sensors**: drag `slot 1 . ax > 1.0 cooldown 2000 ms` into
     the `IF` slot. Change `1.0` → `0.5`.
   - From **LED**: drag `LED slot 5 solid R:255 G:255 B:255 period … dur …`
     into the `THEN` slot. Set `R=255`, `G=0`, `B=0`; leave `period`/`dur`
     at defaults (LED_SOLID ignores the timing fields at the hub level).

   **Path B — raw JSON (recommended for quick testing / LLM-generated rules)**

   - Click the `{ } JSON` toggle in the ECA Rules header. The Blockly host
     is replaced by a textarea seeded with the current workspace's JSON.
   - Paste the golden rule directly:

     ```json
     {
       "version": 1,
       "variables": [],
       "virtual_channels": [],
       "rules": [
         {
           "logic": "AND",
           "conditions": [
             { "ref": { "type": 0, "slot": 1, "ch": 0 },
               "op": "GT", "threshold": 0.5,
               "hold_ms": 0, "cooldown_ms": 2000 }
           ],
           "actions": [
             { "slot": 5, "cmd": "LED_SOLID",
               "p": [255, 0, 0, 255, 0, 0, 0, 0, 0, 0] }
           ]
         }
       ]
     }
     ```

     `ref.type: 0` = `REF.SLOT`, `ch: 0` = `CH.AX`. `cmd` accepts the
     string name (see `eca-encoder.js:49-54`) or the numeric value.
     The `p[]` array is the 10-byte action payload: for LED_SOLID it's
     `[R, G, B, brightness, 0, 0, 0, 0, 0, 0]`.
   - Note: edits in JSON mode do NOT sync back to the Blockly workspace.
     Switching back with `⬛ Blocks` discards JSON edits. Upload while
     the JSON toggle is active — the button uses whichever source mode
     is visible.

4. **Upload**: click `⬆ Upload`. The bridge terminal prints:
   ```
     [sim] P loaded (NN bytes, 0 VCs, 1 rules)
     [sim] ECA running
   ```

5. **Trigger via REPL** (paste into the bridge terminal):
   ```
   spike imu ax 0.8
   ```
   Terminal prints:
   ```
     [sim] ⚡ spike slot=1 ax=0.8 for 50ms
     [sim] ECA fired: slot=5 cmd=1
   ```

6. **Visual confirmation**: click `view` on the **LED module card** in the
   left palette. The sensor panel opens at the bottom. The **LED swatch**
   at the top shows **solid red** with a subtle red glow. `mode` shows
   `solid`. Because LED_SOLID has no duration, the swatch stays red until
   you either send `LED_OFF` manually or clear the program.

7. **Reload-persistence test**: hard-reload the browser tab. The LED swatch should
   come back red after ~100ms (replay via `actuator_cache`).

8. **Cooldown test**: send `spike imu ax 0.8` again within 2 seconds —
   no new `ECA fired` log (cooldown enforced). After 2s, a second spike
   should fire again.

If all eight steps pass, the ECA pipeline is validated end-to-end in
software.

## Manual actuator test (bypasses Blockly)

From the debug console (🔧 floating button):

- Slot: 5, cmd: 1 (LED_SOLID), params: `255 0 0 255 0 0 0 0 0 0`
- Click `send`.
- LED swatch turns red immediately — same dispatch path, just without
  going through bytecode. Useful for isolating engine bugs from UI bugs.

## Troubleshooting

- **"spike" says "unknown channel"**: the channel name must match the
  per-type data key (`ax`/`ay`/`az`/`gx`/`gy`/`gz` for IMU, `bpm`/`spo2`
  for HR, `celsius`/`humidity` for temp, `light` for light sensors).
  See `SIM_CHANNEL_MAP` in `serial_bridge.py`.
- **LED swatch stays red after page reload but no events arrive**: the
  WS `actuator_cache` replay is working. Send `$PC` (clear) from the
  debug console to reset.
- **"ECA fired" log but no LED swatch**: check the browser DevTools
  Network tab for a `{"type":"actuator_state",...}` WS frame. If it's
  present but the swatch is wrong, it's a `wb-sensor-panel.js` bug;
  if absent, it's a `dispatch_action` bug in `serial_bridge.py`.

## Why this port exists

The hub's ECA engine on ESP32 is real and has already been verified
against actual CAN modules (see `WearBlocksECA.cpp` comments). But any
frontend/bytecode iteration that relied only on hardware flashing would
be slow and opaque about which layer failed. This Python port makes
the ECA contract testable in seconds, which unlocks:

- Blockly UX redesign that iterates without a soldering iron nearby.
- LLM Assistant trials (LLM emits JSON rules → sim validates → promote
  to hardware only for confirmed-good programs).
- Cross-checks: if the C++ and Python engines diverge on a golden
  bytecode, one of them has a bug and the mismatch becomes discoverable.

## OSC forwarding (Mode B)

The bridge can fan sensor + actuator events out as UDP/OSC to any
creative-coding host (TouchDesigner, Max/MSP, Pd, Unity). This runs
*in addition* to the WebSocket broadcast — Mode A (Blockly hub program)
and Mode B (OSC sink) are not mutually exclusive.

Configure from the **OSC Forwarding** modal in the status bar (`⤳ OSC`
button). Each target has:

- `host:port` (default `127.0.0.1:7000`)
- `enabled` toggle
- `sensors_filter` — comma-separated sensor types (`imu`, `hr`, ...) or
  slot numbers; empty = pass all sensor messages
- `actuators` — also forward `actuator_state` events
- `rate_limit_hz` — per-OSC-address cap (0 = unlimited)
- mappings table: `source_pattern` → `OSC address` with `scale` + `offset`

Source patterns use slash segments with `*` wildcards:

- `sensor/<slot>/<channel_id>` (e.g. `sensor/3/0`, `sensor/*/0`)
- `actuator/<slot>` (e.g. `actuator/5`, `actuator/*`)

Click **Auto-populate** to generate one mapping per channel for every
plugged-in module (uses live hub schema + `SIM_CHANNEL_MAP`).
Default address scheme: `/hex/<sensor_type>/<slot>/<channel_name>`.

Config persists to `~/.wearblocks/osc_targets.json` and reloads on
bridge restart.

### Smoke test

```bash
python serial_bridge.py --sim --sim-demo
# In another terminal:
oscdump 7000     # liblo, or pip install python-osc and use a dispatcher
```

Add a target `127.0.0.1:7000`, enable, click Auto-populate, and
oscdump should start printing one line per IMU sample.

Limitations (v1): UDP only; per-channel messages only (no bundling);
actuator messages emit the `cmd` code as their scalar arg.

## OSC control return path

The same bridge also listens for external actuator controls. By default it is
loopback-only on `127.0.0.1:7001`; this is independent of forwarding targets.

```text
/hex/control/<uid>/actuator  request_id:string, cmd:int, semantic_params:int...
```

The preferred form always includes a caller-supplied `request_id`. The bridge
validates the UID, command, parameter count, and value ranges, translates the
semantic values to the current ECA-v4 module wire layout, and routes a
correlated `$AO` command through the normal simulator/USB/BLE/Hub path. Legacy
senders may omit the ID; the bridge assigns `legacy-N`.

Replies are unicast to the UDP source port:

```text
/hex/control/<uid>/ack    request_id, stage, detail
/hex/control/<uid>/nack   request_id, stage, reason
/hex/control/<uid>/state  request_id, json_state
```

Every successful request progresses through `queued` and `routed`. The `$AS`
reply carries the Hub's commanded state; for ordinary CAN modules it is marked
unconfirmed because the current CAN action frame has no module-level ACK. A
local motor or simulator can report `applied` immediately. A Wi-Fi module
returns `/wb/ack`, so it also reports `applied`; the Wi-Fi Hub retries a missing
ACK and reports timeout/NACK with the same external request ID.

Supported semantic command arguments:

| cmd | action | parameters |
|---:|---|---|
| `0`, `6` | LED off/stop | none |
| `1` | LED solid | `r g b [duration_ms]` |
| `16` | vibration | `intensity [duration_ms]` |
| `17` | vibration pulse | `intensity on_ms off_ms count` |
| `18` | vibration ramp | `from_pct to_pct [duration_ms]` |
| `19` | vibration stop | none |
| `48` | audio tone | `frequency_hz amplitude [duration_ms]` |
| `49` | audio stop | none |
| `64` | dual motor set | `motor(1/2) mode(0/1/2) speed duration_ms` |

To change the listener:

```bash
python serial_bridge.py --sim-demo \
  --osc-input-host 127.0.0.1 --osc-input-port 7001
```

Binding either OSC direction outside loopback requires the explicit
`--osc-allow-remote` switch.

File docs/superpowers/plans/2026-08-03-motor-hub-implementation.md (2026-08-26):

# Motor Hub Implementation Plan

> **For agentic workers:** REQUIRED SUB-SKILL: Use superpowers:subagent-driven-development (recommended) or superpowers:executing-plans to implement this plan task-by-task. Steps use checkbox (`- [ ]`) syntax for tracking.

**Goal:** Add a BLE/USB-capable one-face motor-hub firmware with locally driven dual motors while retaining the standard hub and external motor module as separate targets.

**Architecture:** Keep `hub/` and `module_motor/` working independently. Add a shared ECA local-actuator dispatch seam, then create `motor_hub/` as a separately compiled hub firmware variant whose built-in motor UID is handled locally and whose external module actions still use CAN.

**Tech Stack:** ESP32-C3 Arduino, C++, WearBlocks CAN/ECA protocol, NimBLE Nordic UART Service, JavaScript Blockly frontend, Python bridge simulator, pytest, Arduino CLI.

## Global Constraints

- Do not push or create a remote PR; all source changes and tests remain local.
- The standard six-face `hardware/firmware/hub/` target must retain its existing hardware behavior.
- The external `hardware/firmware/module_motor/` target must remain supported.
- Motor-hub external Face 1 uses GPIO5; onboard motors use GPIO0/1 and GPIO3/4; CAN uses RX GPIO6 and TX GPIO7; nSLEEP uses GPIO10.
- M1 and M2 state and duration expiry are independent.
- `MOTOR_SET = 64` and payload `[motor, mode, speed, duration_hi, duration_lo]` remain unchanged.
- `nFAULT`, encoders, braking modes, ramps, and closed-loop control remain out of scope.

---

### Task 1: Add a local actuator routing seam to ECA

**Files:**
- Modify: `hardware/firmware/lib/WearBlocksECA/WearBlocksECA.h`
- Modify: `hardware/firmware/lib/WearBlocksECA/WearBlocksECA.cpp`
- Create: `frontend/tools/test_motor_hub_source.mjs`

**Interfaces:**
- Produces: `WBLocalActuatorCallback`, receiving `(targetUid, cmd, payload, payloadLen)` and returning `true` only when handled locally.
- Produces: `WearBlocksECA::setLocalActuatorHandler(WBLocalActuatorCallback)`.
- Preserves: `WearBlocksProtocol::sendActuatorCommand()` as the fallback.

- [ ] **Step 1: Write the failing source-contract test**

Create a Node test that reads the ECA header/source and checks for the callback API, local dispatch before UID-to-slot failure, and the CAN fallback.

```js
assert.match(header, /typedef bool \(\*WBLocalActuatorCallback\)/);
assert.match(header, /setLocalActuatorHandler/);
assert.ok(source.indexOf('_localActuator') < source.indexOf('not registered'));
assert.match(source, /sendActuatorCommand/);
```

- [ ] **Step 2: Run the test and verify it fails**

Run: `node frontend/tools/test_motor_hub_source.mjs`

Expected: FAIL because the local actuator callback does not exist.

- [ ] **Step 3: Implement payload-first local/CAN dispatch**

Add the callback type, setter, and nullable member. Refactor action execution so each command first produces a byte payload. Call the local handler with the target UID; if it returns `true`, stop. Otherwise resolve the UID to a registered slot and emit the same CAN command as before. The standard hub installs no callback, so it remains CAN-only.

- [ ] **Step 4: Run the source-contract and existing protocol tests**

Run `node frontend/tools/test_motor_hub_source.mjs`, `node frontend/tools/test_motor_protocol.mjs`, and `frontend/bridge/.venv/bin/python -m pytest -q frontend/bridge/test_wb_eca.py`.

Expected: all tests pass.

### Task 2: Create the standalone motor-hub firmware

**Files:**
- Create: `hardware/firmware/motor_hub/motor_hub.ino`
- Create: `hardware/firmware/motor_hub/ModuleRegistry.h`
- Create: `hardware/firmware/motor_hub/ModuleRegistry.cpp`
- Preserve: `hardware/firmware/hub/*`
- Preserve: `hardware/firmware/module_motor/module_motor.ino`

**Interfaces:**
- Produces: the same USB/BLE line protocol and NUS UUIDs as `hub/`.
- Produces: a built-in `dual_motor` descriptor keyed by a stable UID derived from the motor-hub ESP32 eFuse MAC.
- Consumes: `WearBlocksECA::setLocalActuatorHandler()` and the existing five-byte `MOTOR_SET` payload.

- [ ] **Step 1: Extend the failing source-contract test**

Assert that `motor_hub.ino` declares GPIO5 as its face pin, initializes NimBLE, registers a local handler, emits `Built-in Dual Motor`, handles `ACT_MOTOR_SET`, and retains `protocol.onHello` for CAN modules.

- [ ] **Step 2: Run the test and verify it fails**

Run: `node frontend/tools/test_motor_hub_source.mjs`

Expected: FAIL because `hardware/firmware/motor_hub/` does not exist.

- [ ] **Step 3: Add the separate firmware target**

Use the existing hub runtime as the behavioral baseline, but keep the files in `motor_hub/`. Change face handling from six pins to one GPIO5 face. Add the DRV8410 PWM driver with boot-safe `nSLEEP` behavior and independent motor timers.

Generate a stable built-in motor UID from the chip UID. Append its `$H`, `$D`, `$I`, and `$T` records during initial synchronization and status/topology snapshots. Use Hub face `0` to mean local/internal, leaving physical Face 1 free.

Register the ECA local handler. Return `true` only for the built-in UID and `ACT_MOTOR_SET`; all other targets fall through to CAN. Apply the same routing to direct `$A` commands.

- [ ] **Step 4: Compile all firmware targets**

Compile `hardware/firmware/hub`, `hardware/firmware/module_motor`, and `hardware/firmware/motor_hub` with `arduino-cli compile --fqbn esp32:esp32:esp32c3 --libraries hardware/firmware/lib`.

Expected: all three commands exit 0.

### Task 3: Model built-in and external motors in the simulator/frontend

**Files:**
- Modify: `frontend/bridge/serial_bridge.py`
- Modify: `frontend/bridge/test_serial_bridge_sim.py`
- Modify: `frontend/js/components/wb-app.js` only if face `0` needs normalization
- Modify: `frontend/js/components/wb-sensor-panel.js` only if the label/state needs differentiation
- Modify: `frontend/tools/test_motor_capability.mjs`

**Interfaces:**
- Produces: a simulator motor-hub with a local `Built-in Dual Motor` that occupies neither a normal slot nor Face 1.
- Preserves: external `Dual DC Motor` simulator behavior and shared capability-based Blockly selection.

- [ ] **Step 1: Write failing simulator tests**

Add assertions that the local motor uses face `0`, Face 1 remains available, built-in UID actions route locally, and external motor UID actions route through the simulated CAN path.

- [ ] **Step 2: Run the focused test and verify it fails**

Run: `frontend/bridge/.venv/bin/python -m pytest -q frontend/bridge/test_serial_bridge_sim.py`

Expected: FAIL because built-in motor-hub state is not modeled.

- [ ] **Step 3: Implement the simulator/frontend distinction**

Retain the external motor module definition. Add a motor-hub simulation definition with a local descriptor, face `0`, and independent motor state. Both descriptors map to the same motor Blockly role, while their display names distinguish them.

- [ ] **Step 4: Run frontend and bridge regressions**

Run all three motor Node tests plus `test_wb_eca.py`, `test_serial_bridge_sim.py`, `test_llm_bridge.py`, and `test_osc_bridge.py`.

Expected: all tests pass.

### Task 4: Document and verify the local implementation

**Files:**
- Modify: `README.md`
- Verify: every file changed by Tasks 1–3

**Interfaces:**
- Documents: separate `hub`, `module_motor`, and `motor_hub` firmware targets and compile commands.

- [ ] **Step 1: Correct repository layout documentation**

List the external motor module alongside module firmware and list `motor_hub` separately as a hub variant.

- [ ] **Step 2: Run syntax and regression verification**

Run Node syntax checks, motor Node tests, the complete bridge pytest suite, `serial_bridge.py --selftest`, and `git diff --check`.

- [ ] **Step 3: Recompile the firmware matrix**

Compile standard hub, external motor module, and motor-hub again and record flash/RAM usage.

- [ ] **Step 4: Review the local diff without pushing**

Run `git status --short`, `git diff --stat`, and focused diffs. Confirm unrelated existing user files remain untouched. Do not run `git push`.

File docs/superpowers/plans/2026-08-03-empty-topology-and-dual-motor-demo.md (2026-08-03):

# Empty Topology and Dual Motor Demo Implementation Plan

> **For agentic workers:** REQUIRED SUB-SKILL: Use superpowers:subagent-driven-development (recommended) or superpowers:executing-plans to implement this plan task-by-task. Steps use checkbox (`- [ ]`) syntax for tracking.

**Goal:** Hide the topology's synthetic Hub until a real/simulated Hub context exists and add a live-targeted dual-motor Blockly demo.

**Architecture:** A small pure helper derives Hub presence from physical transport state and visible modules, and `wb-app` passes that result to the palette and topology canvas. The D4 preset uses a demo-state factory that binds both motor actions to the first active motor-capable UID after the simulator attaches `motor_hub`.

**Tech Stack:** Lit web components, Blockly workspace JSON, Node.js assertion scripts, Python asyncio simulator, pytest.

## Global Constraints

- Keep all changes local; do not push.
- Preserve Night Light, Theremin, and Motion Alert behavior.
- Motor 1 and Motor 2 must remain independently configurable.
- Use only direction, speed, stop/start, and duration controls; no encoder layer.

---

### Task 1: Hub Presence State

**Files:**
- Create: `frontend/js/hub-presence.js`
- Create: `frontend/tools/test_hub_presence.mjs`
- Modify: `frontend/js/components/wb-app.js`
- Modify: `frontend/js/components/wb-palette.js`
- Modify: `frontend/js/components/wb-block-canvas.js`

**Interfaces:**
- Consumes: `{connected: boolean}` transport status and the visible module array.
- Produces: `hasHubPresence(transport, modules): boolean` and `hubPresent` Lit properties on the two topology components.

- [ ] **Step 1: Write the failing pure-state test**

Create assertions that no transport plus no modules is false, connected transport plus no modules is true, and no transport plus one simulator module is true.

- [ ] **Step 2: Run the test to verify it fails**

Run: `node frontend/tools/test_hub_presence.mjs`

Expected: FAIL because `frontend/js/hub-presence.js` does not exist.

- [ ] **Step 3: Implement the state helper and pass the property through `wb-app`**

Implement:

```js
export function hasHubPresence(transport, modules = []) {
  return !!transport?.connected || modules.length > 0;
}
```

Compute it from `_transport` and `visibleModules`, then bind `.hubPresent` on `wb-palette` and `wb-block-canvas`.

- [ ] **Step 4: Render the disconnected empty state**

Give both components a Boolean `hubPresent` property defaulting to `false`. Omit the Hub row, central Hub, faces, and topology controls while false, and render the copy `Connect a hub to begin`.

- [ ] **Step 5: Run the test to verify it passes**

Run: `node frontend/tools/test_hub_presence.mjs`

Expected: PASS with `hub presence: ok`.

### Task 2: Dual Motor Demo State

**Files:**
- Create: `frontend/tools/test_dual_motor_demo.mjs`
- Modify: `frontend/js/demo-programs.js`
- Modify: `frontend/js/components/wb-status-bar.js`
- Modify: `frontend/js/components/wb-app.js`
- Modify: `frontend/js/ws-client.js`

**Interfaces:**
- Consumes: active frontend module records and `moduleHasRole(module, 'motor')`.
- Produces: `getDemoProgram(name, modules)` returning Blockly workspace JSON whose D4 motor targets use a live motor UID when available.

- [ ] **Step 1: Write the failing demo-state test**

Assert that `getDemoProgram('demo4', [motorModule])` returns one rule with chained `motor_action` blocks targeting the same live UID, with M1/forward/160/2000 and M2/reverse/120/3000 fields.

- [ ] **Step 2: Run the test to verify it fails**

Run: `node frontend/tools/test_dual_motor_demo.mjs`

Expected: FAIL because D4 and `getDemoProgram` do not exist.

- [ ] **Step 3: Implement the D4 factory**

Add `DEMO_D4`, include `demo4` in `DEMO_PROGRAMS`, and export `getDemoProgram(name, modules)`. Clone the stored state before replacing both motor `SLOT` fields with the first active motor-capable module UID.

- [ ] **Step 4: Add the D4 status-bar button**

Pass visible modules from `wb-app` to `wb-status-bar`. Add `D4 Dual Motor Test`, send `demo4` to the simulator, and call `getDemoProgram` after the existing discovery delay so the live motor UID is available.

- [ ] **Step 5: Run the test to verify it passes**

Run: `node frontend/tools/test_dual_motor_demo.mjs`

Expected: PASS with `dual motor demo: ok`.

### Task 3: Simulator Preset

**Files:**
- Modify: `frontend/bridge/test_serial_bridge_sim.py`
- Modify: `frontend/bridge/serial_bridge.py`

**Interfaces:**
- Consumes: `sim_clear_all()` and `sim_add_module('motor_hub')`.
- Produces: `async sim_run_demo_d4()` and `demo4`/`d4` simulator command routing.

- [ ] **Step 1: Write the failing simulator test**

Monkeypatch the clear/add helpers, run `sim_run_demo_d4()`, and assert the call sequence is `clear`, then `motor_hub`.

- [ ] **Step 2: Run the test to verify it fails**

Run: `frontend/bridge/.venv/bin/python -m pytest -q frontend/bridge/test_serial_bridge_sim.py -k demo_d4`

Expected: FAIL because `sim_run_demo_d4` does not exist.

- [ ] **Step 3: Implement and route D4**

Clear the simulator, wait briefly, attach `motor_hub`, and accept both `demo4` and `d4` in the command handler.

- [ ] **Step 4: Run the focused simulator test**

Run: `frontend/bridge/.venv/bin/python -m pytest -q frontend/bridge/test_serial_bridge_sim.py -k demo_d4`

Expected: PASS.

### Task 4: Regression Verification

**Files:**
- Modify only if a regression is discovered in an in-scope file.

**Interfaces:**
- Consumes: all changes from Tasks 1-3.
- Produces: verified frontend and bridge behavior without publishing changes.

- [ ] **Step 1: Run all focused frontend tests**

Run: `node frontend/tools/test_hub_presence.mjs && node frontend/tools/test_dual_motor_demo.mjs && node frontend/tools/test_motor_protocol.mjs && node frontend/tools/test_motor_capability.mjs`

Expected: all print `ok` and exit 0.

- [ ] **Step 2: Run the bridge suite**

Run: `frontend/bridge/.venv/bin/python -m pytest -q frontend/bridge`

Expected: all tests pass.

- [ ] **Step 3: Inspect the local diff**

Run: `git diff --check` and `git status --short`.

Expected: no whitespace errors; only local files are changed and nothing is pushed.

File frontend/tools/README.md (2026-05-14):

# frontend/tools/

Operator-side helpers that don't fit in the bridge or the browser.

## `wb_debug.py`

High-signal debug monitor for the hub. Renders a colored event timeline
plus a 6-cell face-occupancy bar; suppresses the high-rate `$S` sensor
stream (counted as a rate); single-key shortcuts for `$Q,STATUS` /
`$Q,TOPO` and ECA program controls.

Two modes — pick one:

```bash
# Direct serial (bridge MUST NOT be holding the port)
python3 wb_debug.py --port /dev/cu.usbserial-11201

# Auto-discover a serial port whose name contains "11201"
python3 wb_debug.py --port auto --hint 11201

# WebSocket client to a running bridge (coexists with the frontend)
python3 wb_debug.py --ws ws://localhost:8765

# Inspect available ports
python3 wb_debug.py --list
```

Keys (both modes): `t` topology, `s` status, `r` run program, `p` stop,
`c` clear, `q` quit. `--raw` shows everything (no filtering).

Dependencies: `pyserial` for `--port`, `websockets` for `--ws`. Both come
in via the bridge's existing requirements.

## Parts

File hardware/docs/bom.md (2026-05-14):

# WearBlocks Hardware BOM

> Reflects the prototype shipping on `main` as of 2026-04. Hub is
> ESP32-C3-MINI-1 (not S3); PosID is **digital presence** (per-face
> pull-up on hub + GND tie on the module's docking face), so there is
> **no resistor ladder** on either side. See `pin-assignment.md` and
> `posid-topology.md` for the wiring rationale.

## Hub (1 unit)

| # | Component | Part Number | Qty | Unit Cost | Subtotal | Source |
|---|---|---|-----|---|---|---|
| 1 | MCU | ESP32-C3-MINI-1-N4 | 1 | $1.50 | $1.50 | LCSC |
| 2 | CAN Transceiver | SN65HVD230DR | 1 | $0.50 | $0.50 | LCSC |
| 3 | USB-C Connector | USB-C 16-pin SMD | 1 | $0.30 | $0.30 | LCSC |
| 4 | LiPo Charger | TP4056 module | 1 | $0.50 | $0.50 | LCSC |
| 5 | 3.3V Regulator | AMS1117-3.3 | 1 | $0.10 | $0.10 | LCSC |
| 6 | LiPo Battery | 3.7V 1000mAh w/ JST | 1 | $3.00 | $3.00 | Amazon |
| 7 | PosID Pull-ups (6 faces) | 10kΩ 0603 | 6 | $0.01 | $0.06 | LCSC |
| 8 | Pogo Pins (6-pin × 6 faces) | P75-B1 spring-loaded | 36 | $0.10 | $3.60 | AliExpress |
| 9 | Neodymium Magnets | 6mm × 2mm N52 disc | 12 | $0.10 | $1.20 | AliExpress |
| 10 | PCB (hex shape) | JLCPCB 2-layer | 1 | $1.00 | $1.00 | JLCPCB |
| 11 | 3D Printed Enclosure | PLA, white/gray | 1 | $0.50 | $0.50 | Self |
| 12 | Misc (caps, LEDs, headers) | Various 0603 | – | $1.00 | $1.00 | LCSC |
| | | | | **Hub Total** | **$13.26** | |

## Per-Module Base (× 6 module types)

Common to every module before the sensor/actuator add-on.

| # | Component | Part Number | Qty | Unit Cost | Subtotal | Source |
|---|---|---|-----|---|---|---|
| 1 | MCU | ESP32-C3-MINI-1-N4 | 1 | $1.50 | $1.50 | LCSC |
| 2 | CAN Transceiver | SN65HVD230DR | 1 | $0.50 | $0.50 | LCSC |
| 3 | PosID GND traces (6 faces) | trace + pad | 6 | $0.00 | $0.00 | PCB |
| 4 | Pogo Pins (6-pin × 2–3 active faces) | P75-B1 | 12–18 | $0.10 | $1.50 | AliExpress |
| 5 | Neodymium Magnets | 6mm × 2mm N52 | 4–6 | $0.10 | $0.50 | AliExpress |
| 6 | PCB (hex shape) | JLCPCB 2-layer | 1 | $0.50 | $0.50 | JLCPCB |
| 7 | 3D Printed Enclosure | PLA, color-coded | 1 | $0.50 | $0.50 | Self |
| 8 | Misc (caps, headers) | Various 0603 | – | $0.50 | $0.50 | LCSC |
| | | | | **Base Module** | **$5.50** | |

## Sensor / Actuator Add-on (per module type)

Identity columns (`module name`, `descriptor color`) match what the hub
emits in `$H` and what the frontend renders on the canvas. Folder paths
are under `hardware/firmware/`.

| Module | Folder | Identity → name / color | Sensor/Actuator | Breakout | Add-on Cost |
|---|---|---|---|---|---|
| IMU | `module_imu/` | 6-Axis IMU / `#7CA1BB` Slate | MPU6050 6-axis | GY-521 | $1.50 |
| LED | `module_led/` | RGB LED / `#C68E9E` Rose | WS2812B × 8 | NeoPixel Ring 8 | $2.50 |
| Vibration | `module_vibration/` | Vibration Motor / `#50C878` Green | ERM motor + DRV2605L | DRV2605L breakout + motor | $4.00 |
| Audio Synth | `module_amplifier/` | Audio Synth / `#9885BF` Purple | MAX98357A I2S amp + 8Ω speaker | MAX98357A breakout + speaker | $3.50 |
| Light Sensor | `module_light_resistor/` | Light Sensor / `#C1B496` Tan | GL5528 LDR + 10kΩ divider | discrete | $0.50 |
| Rotary Knob | `module_resistor/` | Rotary Knob / `#98AF6F` Olive | WH148 B100K rotary pot | discrete | $0.80 |

> Note on the two greens: vibration uses `#50C878` (sea green), knob uses
> `#98AF6F` (olive). They are deliberately distinct on the canvas; if you
> change one, update the other so they don't collide.

## Total Project Cost

| Item | Cost |
|---|---|
| Hub × 1 | $13.26 |
| IMU module | $7.00 |
| LED module | $8.00 |
| Vibration module | $9.50 |
| Audio Synth module | $9.00 |
| Light Sensor module | $6.00 |
| Rotary Knob module | $6.30 |
| Spare parts / shipping | ~$20.00 |
| **Grand Total** | **~$79** |

## Ordering Checklist

- [ ] LCSC: ESP32-C3-MINI-1 ×7, SN65HVD230 ×7, 10kΩ pull-ups, caps, AMS1117-3.3, TP4056, USB-C
- [ ] AliExpress: P75-B1 pogo pins ×100, 6mm×2mm N52 magnets ×50
- [ ] Sensor/actuator breakouts: GY-521, NeoPixel Ring 8, DRV2605L + ERM, MAX98357A + 8Ω speaker, GL5528 LDR, WH148 B100K
- [ ] JLCPCB: Hub PCB ×2, Module PCB ×10
- [ ] 3D printing filament: white/gray (hub) + Blue / Coral / Green / Teal / Yellow / Lime PLA (one per module type)
- [ ] LiPo battery: 3.7V 1000mAh with JST connector

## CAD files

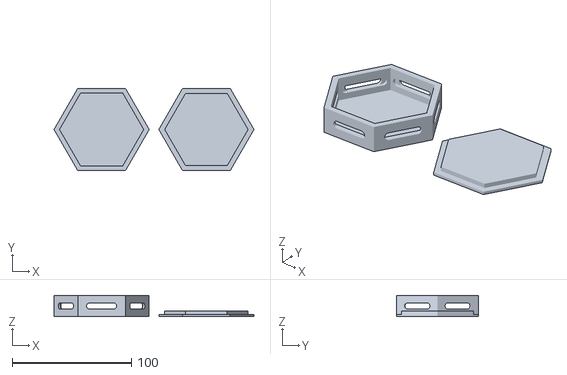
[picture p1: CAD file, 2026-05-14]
openscad-model/hex_module.stl
168.0 x 69.3 x 18.0

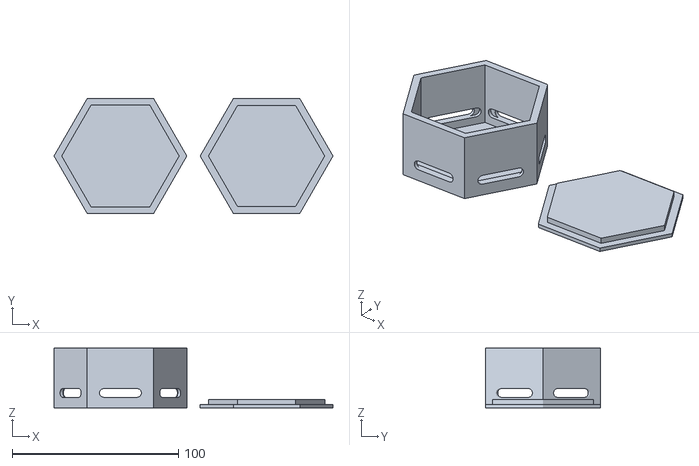
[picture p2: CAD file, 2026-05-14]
openscad-model/hex_module_h36.stl
168.0 x 69.3 x 36.0

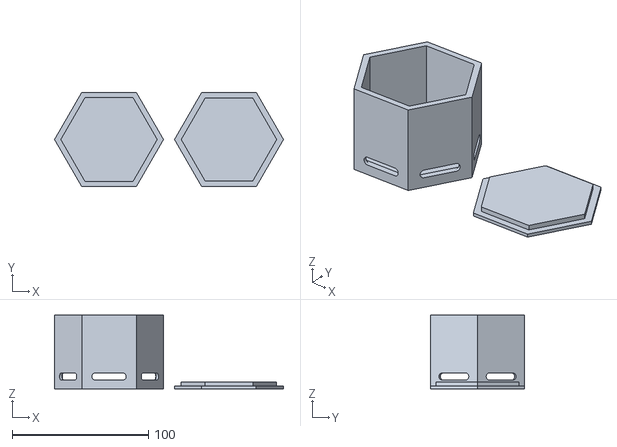
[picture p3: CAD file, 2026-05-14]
openscad-model/hex_module_h54.stl
168.0 x 69.3 x 54.0

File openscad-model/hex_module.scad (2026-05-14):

// Hex module enclosure with 6-side pogopin boards
// All units in mm

/* ---------- parameters ---------- */

// Hex body
edge_outer   = 40.0;   // outer edge length of hex
body_h       = 18.0;   // body height (excluding cap)
// Wall
wall_t         = 4.0;    // wall thickness = outer_slot_depth + pocket_depth

// Pogopin module (stepped obround profile) on each of 6 faces
// --- outer step: embedded into the wall, pogopin-exposing slot ---
outer_slot_len   = 24.8;   // total length incl. both φ end-circles
outer_slot_dia   = 4.8;    // height / end-circle diameter
outer_slot_depth = 2.0;    // embedded depth (from outer face)

// --- inner step: flange sitting inside the wall, includes mounting ears ---
inner_pocket_len   = 30.6;
inner_pocket_dia   = 4.8;
inner_pocket_depth = 2.0;  // recess depth from inner wall face

pocket_clear   = 0.2;      // clearance added per side vs nominal module size

board_z_c      = 9.0;      // slot vertical center (Z) -- consistent across modules

// Base plate & cap
base_t       = 2.0;    // floor thickness (internal floor of hex body)
cap_plug_h   = 3.0;    // how deep the cap plug sits into body
cap_top_h    = 2.0;    // cap lid thickness above the plug
cap_clear    = 0.3;    // clearance on each side between plug and body

// Rendering
$fn = 96;

/* ---------- derived ---------- */
// hex inscribed (apothem) = edge * sqrt(3)/2
apothem_outer = edge_outer * sqrt(3) / 2;
edge_inner    = edge_outer - 2 * wall_t / (sqrt(3)/2);
                // shrinking apothem by wall_t -> edge shrinks by wall_t*2/sqrt(3)... but we use
                // a simpler approach: subtract a smaller hex prism scaled by apothem
apothem_inner = apothem_outer - wall_t;

/* ---------- helpers ---------- */

// regular hexagon centered at origin, flat side facing +Y
module hex_prism(edge, h) {
    // built from 6 rotated rectangles -> use cylinder $fn=6 for simplicity
    // cylinder r=edge, $fn=6 gives hex with edge length = r
    cylinder(h = h, r = edge, $fn = 6, center = false);
}

// inner hex cavity by apothem (distance from center to flat face)
module hex_prism_by_apothem(apothem, h) {
    // edge length e where apothem = e*sqrt(3)/2  =>  e = apothem*2/sqrt(3)
    e = apothem * 2 / sqrt(3);
    hex_prism(e, h);
}

/* ---------- feature: obround pogopin slot on one face (face along +Y) ---------- */
// 2D obround: hull of two circles, length=slot_len, diameter=slot_dia
module obround_2d(length, dia) {
    r = dia / 2;
    hull() {
        translate([-(length/2 - r), 0]) circle(r = r);
        translate([ (length/2 - r), 0]) circle(r = r);
    }
}

// Cut the stepped slot on one face (face at y = +apothem_outer, normal = +Y).
// Outer step (24.8): punches from outer face inward by outer_slot_depth.
// Inner step (30.6): recess from inner face outward by inner_pocket_depth.
module face_slot_cut() {
    // outer step -- from outer face (y = apothem_outer) going inward
    translate([0, apothem_outer + 0.01, board_z_c])
        rotate([90, 0, 0])
            linear_extrude(height = outer_slot_depth + 0.02)
                obround_2d(outer_slot_len + 2*pocket_clear,
                           outer_slot_dia + 2*pocket_clear);

    // inner step (flange pocket) -- from inner face (y = apothem_outer - wall_t) going outward
    translate([0, apothem_outer - wall_t + inner_pocket_depth + 0.01, board_z_c])
        rotate([90, 0, 0])
            linear_extrude(height = inner_pocket_depth + 0.02)
                obround_2d(inner_pocket_len + 2*pocket_clear,
                           inner_pocket_dia + 2*pocket_clear);
}

/* ---------- main body ---------- */

module hex_body() {
    difference() {
        // outer solid
        hex_prism(edge_outer, body_h);

        // inner cavity (leave base_t floor)
        translate([0, 0, base_t])
            hex_prism_by_apothem(apothem_inner, body_h - base_t + 1);

        // cut obround slot on all 6 faces
        for (i = [0:5])
            rotate([0, 0, 60 * i])
                face_slot_cut();
    }
}

/* ---------- cap (plug style) ---------- */

module cap() {
    // top lid sitting above body, with a plug going down into the body opening
    translate([0, 0, 0]) {
        // lid (slightly larger than body to act as a lip) -- keep flush if you prefer
        hex_prism(edge_outer, cap_top_h);
        // plug that fits into the inner hex cavity
        translate([0, 0, -cap_plug_h])
            hex_prism_by_apothem(apothem_inner - cap_clear, cap_plug_h + 0.01);
    }
}

/* ---------- layout ---------- */

// body
hex_body();

// cap (shifted to the side for printing preview; move on top to check fit)
translate([edge_outer * 2.2, 0, cap_top_h])
    rotate([180, 0, 0])
        cap();

// --- uncomment to preview cap assembled on body ---
// translate([0, 0, body_h + cap_top_h]) rotate([180,0,0]) cap();

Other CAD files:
openscad-model/hex_module_h36.scad
openscad-model/hex_module_h54.scad

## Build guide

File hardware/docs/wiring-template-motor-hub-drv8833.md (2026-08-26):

## 1. 模块概览

- **模块名称**：`motor_hub`
- **角色**：`<hub + local motor output>`
- **驱动器**：`<DRV8833 motor driver module>`
- **负载**：`<2x DC motor>`
- **CAN 收发器**：`<SN65HVD230>`
- **6-pin 磁吸触点数量**：`<1 母>`
- **DRV8833 驱动小板接口**：`<两侧各 6-pin 排针>`

说明：这是一个新的带 motor 的 hub 形态，不是在现有 hub PCB 上飞线改造，也不是普通可堆叠 motor module。它本身作为 CAN hub/root，只保留 1 个磁吸母头 face 给其他模块接入；motor 由本 hub 板上的 ESP32-C3 直接控制一块现成 DRV8833 驱动小板。

---

## 2. 6-pin 磁吸触点定义

磁吸触点（母头，用于接入其他模块）

| Pin # | 信号 | 说明 |
|---|---|---|
| 1 | VCC (3.3V) | 给外接模块提供逻辑电源 |
| 2 | GND | 共地 |
| 3 | CAN-H | CAN 总线高 |
| 4 | CAN-L | CAN 总线低 |
| 5 | POS_ID | 接 ESP32-C3 GPIO0，用于检测外接模块接入 |
| 6 | POS_GND | 共地 |

没有磁吸公头：`motor_hub` 是拓扑 root，不需要插到其他 hub 或父模块上。

---

## 3. ESP32-C3 引脚分配

| GPIO | 用途 | 接到哪 | 备注 |
|---|---|---|---|
| GPIO7 | TWAI_TX | SN65HVD230 `TXD` | 以当前 `hardware/firmware/hub/hub.ino` 为准 |
| GPIO6 | TWAI_RX | SN65HVD230 `RXD` | 以当前 `hardware/firmware/hub/hub.ino` 为准 |
| GPIO0 | Face 1 presence | 磁吸母头 `POS_ID` | `INPUT_PULLUP`，低电平表示有模块接入；boot strapping pin |
| GPIO1 | `MOTOR_IN1` | DRV8833 驱动小板 `IN1` | Motor 1 输入 1，可输出 PWM |
| GPIO2 | `MOTOR_IN2` | DRV8833 驱动小板 `IN2` | Motor 1 输入 2，可输出 PWM；boot strapping pin |
| GPIO3 | `MOTOR_IN3` | DRV8833 驱动小板 `IN3` | Motor 2 输入 1，可输出 PWM |
| GPIO4 | `MOTOR_IN4` | DRV8833 驱动小板 `IN4` | Motor 2 输入 2，可输出 PWM |
| GPIO9 | Status LED | 可选 | 若不用状态灯可空置 |

> 如果后续决定沿用旧文档中的 CAN 方向（GPIO6=TX、GPIO7=RX），需要同步修改 `hub.ino` 里的 `CAN_TX_PIN` / `CAN_RX_PIN`，不要只改硬件或只改固件。
>
> `GPIO0` 和 `GPIO2` 是 ESP32-C3 boot strapping pins。`GPIO0` 作为 face detect 时，如果外接模块在上电瞬间把 `POS_ID` 拉低，可能影响启动。bring-up 时建议先空 face 上电，等 hub 启动完成后再插模块。

---

## 4. CAN 收发器接线（`SN65HVD230`）

| 收发器引脚 | 接到 | 备注 |
|---|---|---|
| TXD | ESP32-C3 GPIO7 | `TWAI_TX` |
| RXD | ESP32-C3 GPIO6 | `TWAI_RX` |
| VCC | 3.3V 主电源轨 | 与 ESP32-C3 同电源 |
| GND | GND | 共地 |
| CANH | 磁吸母头 `CAN-H` | 通过唯一 face 接入外部模块 |
| CANL | 磁吸母头 `CAN-L` | 通过唯一 face 接入外部模块 |
| Rs | GND | 高速模式 |
| Vref | NC | 不使用 |

CAN 总线终端仍建议放在 hub/root 侧：`CAN-H` 与 `CAN-L` 之间接 120Ω。

---

## 5. DRV8833 驱动小板接线

这里使用 Simple Circuit 页面中的 DRV8833 驱动小板，而不是裸 DRV8833 芯片。该小板共 12 个 pin，两侧各 6 个，丝印包括 `VCC`、`GND`、`EEP`、`ULT`、`IN1`、`IN2`、`IN3`、`IN4`、`OUT1`、`OUT2`、`OUT3`、`OUT4`。

### 5.1 控制/状态 pin

| DRV8833 小板丝印 | 接到 | 备注 |
|---|---|---|
| `VCC` | Motor 电源正极 | 这是该小板的 motor supply，不是单独的 3.3V logic pin |
| `GND` | `motor_hub` GND + motor 电源负极 | 必须与 ESP32-C3、CAN、磁吸 GND 共地 |
| `EEP` | NC | 该小板已用 47k 上拉到 `VCC`，默认启用；拉到 GND 才进入 sleep |
| `ULT` | NC | `FAULT` 输出，本版按计划悬空 |
| `IN1` | ESP32-C3 GPIO1 | Motor 1 输入 1，`MOTOR_IN1` |
| `IN2` | ESP32-C3 GPIO2 | Motor 1 输入 2，`MOTOR_IN2` |
| `IN3` | ESP32-C3 GPIO3 | Motor 2 输入 1，`MOTOR_IN3` |
| `IN4` | ESP32-C3 GPIO4 | Motor 2 输入 2，`MOTOR_IN4` |

`EEP` 不需要再接电阻到 3.3V。这个模块板上已经把 `EEP` 通过 47k 上拉到 `VCC`；如果 motor 电源 `VCC` 高于 3.3V，不要把 `EEP` 直接接到 ESP32-C3 GPIO。后续若要用 MCU 控制 sleep，建议用小信号 NMOS / NPN 做开漏下拉：平时放开让板载 47k 上拉，需要 sleep 时把 `EEP` 拉到 GND。

### 5.2 电机输出 pin

| DRV8833 小板丝印 | 接到 | 备注 |
|---|---|---|
| `OUT1` | Motor 1 `M+` | 电机两端可对调；对调后正反方向互换 |
| `OUT2` | Motor 1 `M-` | 电机两端可对调 |
| `OUT3` | Motor 2 `M+` | 电机两端可对调；对调后正反方向互换 |
| `OUT4` | Motor 2 `M-` | 电机两端可对调 |

> 不建议用磁吸触点上的 3.3V 直接给 motor 供电。磁吸 3.3V 只给外接模块、ESP32-C3 和 CAN 收发器使用；DRV8833 小板的 `VCC` 建议走独立电池或独立稳压电源，并与 `motor_hub` 共地。

---

## 6. Motor 控制真值表

Motor 1 使用 `IN1/IN2`，Motor 2 使用 `IN3/IN4`。两路控制逻辑相同：

| INx1 | INx2 | Motor 状态 | 说明 |
|---|---|---|---|
| LOW | LOW | 滑行停止 | 输出高阻，电机自由滑行 |
| HIGH | LOW | 正转 | 方向取决于 M1+/M1- 接法 |
| LOW | HIGH | 反转 | 方向取决于 M1+/M1- 接法 |
| HIGH | HIGH | 刹车 | 两端短刹，停止更快，电流更大 |

调速建议：

| 目标 | 推荐做法 |
|---|---|
| Motor 1 正转调速 | `IN1 = PWM`，`IN2 = LOW` |
| Motor 1 反转调速 | `IN1 = LOW`，`IN2 = PWM` |
| Motor 2 正转调速 | `IN3 = PWM`，`IN4 = LOW` |
| Motor 2 反转调速 | `IN3 = LOW`，`IN4 = PWM` |
| 停止滑行 | 对应 motor 的两个输入都设为 `LOW` |
| 短刹车 | 对应 motor 的两个输入都设为 `HIGH`，短时间后回到 `LOW/LOW` |

---

## 7. 固件影响

后续做固件时，这块板应从 hub 固件派生，而不是从普通 module 固件派生：

| 项目 | 建议 |
|---|---|
| CAN 角色 | hub/root，继续主动枚举外接模块 |
| Face 数量 | 只扫描 1 个 face：`GPIO0` |
| Motor 输出 | 在 hub 本地增加两路 motor actuator 控制逻辑，不通过 CAN 发送给另一个 motor module |
| 拓扑 | 外接模块都挂在 `motor_hub` 的唯一 face 上 |

最小初始化方向：

```cpp
#define FACE1_PIN 0
#define MOTOR_IN1_PIN 1
#define MOTOR_IN2_PIN 2
#define MOTOR_IN3_PIN 3
#define MOTOR_IN4_PIN 4

pinMode(MOTOR_IN1_PIN, OUTPUT);
pinMode(MOTOR_IN2_PIN, OUTPUT);
pinMode(MOTOR_IN3_PIN, OUTPUT);
pinMode(MOTOR_IN4_PIN, OUTPUT);
digitalWrite(MOTOR_IN1_PIN, LOW);
digitalWrite(MOTOR_IN2_PIN, LOW);
digitalWrite(MOTOR_IN3_PIN, LOW);
digitalWrite(MOTOR_IN4_PIN, LOW);

pinMode(FACE1_PIN, INPUT_PULLUP);
```

---

## 8. 电源与保护

| 项目 | 建议 |
|---|---|
| 逻辑电源 | ESP32-C3、SN65HVD230、磁吸外接模块使用 3.3V |
| Motor 电源 | 单独接到 DRV8833 小板 `VCC`，不要直接从 ESP32-C3 GPIO 或 3.3V LDO 取电 |
| 共地 | motor 电源 GND、DRV8833 小板 GND、ESP32-C3 GND、磁吸 GND 必须连接 |
| 去耦 | DRV8833 小板 `VCC` 和 `GND` 旁放 10uF 以上电容 |
| 电机噪声 | 电机两端可并 0.1uF 陶瓷电容；motor 线远离 CAN-H/CAN-L |
| 电流 | 两个电机同时堵转时，总电流不能超过 DRV8833 小板和 motor 电源的能力 |

---

## 9. Bring-up 检查清单

- [ ] 不接 motor，只接 ESP32-C3 + SN65HVD230，确认 hub 能正常启动。
- [ ] 空 face 上电，确认 hub 能正常启动；再插入一个普通模块到唯一磁吸母头，确认 `GPIO0` 可检测到接入，hub 能收到模块 HELLO。
- [ ] 不接 motor，只接 DRV8833 驱动小板，确认 `EEP` 未被拉低；该小板默认通过 47k 上拉启用。
- [ ] 确认 DRV8833 驱动小板 GND、ESP32-C3 GND、motor 电源 GND、磁吸 GND 共地。
- [ ] 使用限流电源给 DRV8833 小板 `VCC` 供电，限流从较低值开始。
- [ ] 固件先分别测试 Motor 1 和 Motor 2 的 `LOW/LOW`，再测 `HIGH/LOW` 和 `LOW/HIGH`。
- [ ] 最后再测试每个 motor 的 `HIGH/HIGH` 刹车，避免长时间刹车导致电流过大。
- [ ] motor 转动时观察外接模块的 CAN 通信是否稳定；若掉线，增加去耦并让 motor 线远离 CAN 线。

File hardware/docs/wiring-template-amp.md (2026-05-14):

## 1. 模块概览
- **模块名称**：`module_amplifier`
- **角色**：`<output module>`
- **传感器**：`<MAX98357A>`，
- **CAN 收发器**：`<SN65HVD230>`
- **6-pin 磁吸触点数量**：`<1 公 + 1 母>`
---

## 2. 6-pin 磁吸触点定义

磁吸触点（母头）

| Pin # | 信号 | 说明 |
|---|---|---|---|
| 1 | VCC (3.3V) | 供电 (红色靠外)|
| 2 | GND| 共地（红色靠内）|
| 3 | CAN—H|  | （黄色） |
| 4 | CAN-L|  | （黄色右侧黑色） |
| 5 | POS_ID | | GPIO 10，用于检测新接入的模块(下数第三个pin)（一般为蓝色）|
| 6 | POS_GND | | 共地 |
---

磁吸触点（公头）
| Pin # | 信号 | 说明 |
|---|---|---|---|
| 1 | VCC (3.3V) | 供电 (红色靠外)|
| 2 | GND| 共地（红色靠内）|
| 3 | CAN—H|  | （黄色） |
| 4 | CAN-L|  | （黄色右侧黑色） |
| 5 | POS_ID | GND | 共地（一般为蓝色）|
| 6 | POS_GND | GND | 共地 |
---

## 3. ESP32-C3 引脚分配

| GPIO | 用途 | 接到哪 | 备注 |
|---|---|---|---|
| GPIO6 | TWAI_TX | `<CAN_IC>` 的 TXD | |
| GPIO7 | TWAI_RX | `<CAN_IC>` 的 RXD | |
| GPIO10 | 连接磁吸传感器母头检测其他传感器接入状态| `<>` | |
| GPIO5 | 连接放大器BCLK| `<>` | 位时钟 (避开 strapping pin GPIO2) |
| GPIO3 | 连接放大器LRC| `<>` | |
| GPIO4 | 连接放大器DIN| `<>` | |

## 4. CAN 收发器接线（`<SN65HVD230>`）

| 收发器引脚 | 接到 |
|---|---|
| TXD | ESP32 GPIO6 |
| RXD | ESP32 GPIO7 |
| VCC | 3.3V 主电源轨 |
| GND | GND |
| CANH | 通过磁吸触点连接|
| CANL | 通过磁吸触点连接|

---

## 5. 传感器接线

| 传感器引脚 | 接到 | 备注 |
|---|---|---|
| VCC | 3.3V | |
| GND | GND | |
| BCLK | GPIO 5 |位时钟输入（避开 strapping pin GPIO2）|
| LRC | GPIO 3 |左右通道式中|
| DIN | GPIO 4 |数据输入|

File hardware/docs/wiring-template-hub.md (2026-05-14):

## 1. 模块概览
- **模块名称**：`module_hub`
- **角色**：`<hub module>`
- **传感器**：``，
- **CAN 收发器**：`<SN65HVD230>`
- **6-pin 磁吸触点数量**：`<2 母>`
---

## 2. 6-pin 磁吸触点定义

磁吸触点（母头x2）

| Pin # | 信号 | 说明 |
|---|---|---|---|
| 1 | VCC (3.3V) | 供电 (红色靠外)|
| 2 | GND| 共地（红色靠内）|
| 3 | CAN—H|  | （黄色） |
| 4 | CAN-L|  | （黄色右侧黑色） |
| 5 | POS_ID | | 接入任意可用GPIO PIN(0,2,3,4,8,10)|
| 6 | POS_GND | | 共地 |
---

## 3. ESP32-C3 引脚分配

| GPIO | 用途 | 接到哪 | 备注 |
|---|---|---|---|
| GPIO6 | TWAI_TX | `<CAN_IC>` 的 TXD | |
| GPIO7 | TWAI_RX | `<CAN_IC>` 的 RXD | |
| GPIO0/2/3/4/8/10 | 连接磁吸传感器母头检测其他传感器接入状态| `<>` | |

## 4. CAN 收发器接线（`<SN65HVD230>`）

| 收发器引脚 | 接到 |
|---|---|
| TXD | ESP32 GPIO6 |
| RXD | ESP32 GPIO7 |
| VCC | 3.3V 主电源轨 |
| GND | GND |
| CANH | 通过磁吸触点连接|
| CANL | 通过磁吸触点连接|

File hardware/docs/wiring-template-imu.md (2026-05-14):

## 1. 模块概览
- **模块名称**：`module_imu`
- **角色**：`<sensor module>`
- **传感器**：`<MPU6050>`，
- **CAN 收发器**：`<SN65HVD230>`
- **6-pin 磁吸触点数量**：`<1 母 + 1 公>`
---

## 2. 6-pin 磁吸触点定义

磁吸触点（母头）

| Pin # | 信号 | 说明 |
|---|---|---|---|
| 1 | VCC (3.3V) | 供电 (红色靠外)|
| 2 | GND| 共地（红色靠内）|
| 3 | CAN—H|  | （黄色） |
| 4 | CAN-L|  | （黄色右侧黑色） |
| 5 | POS_ID | | GPIO 10，用于检测新接入的模块(下数第三个pin)（一般为蓝色）|
| 6 | POS_GND | | 共地 |
---

磁吸触点（公头）
| Pin # | 信号 | 说明 |
|---|---|---|---|
| 1 | VCC (3.3V) | 供电 (红色靠外)|
| 2 | GND| 共地（红色靠内）|
| 3 | CAN—H|  | （黄色） |
| 4 | CAN-L|  | （黄色右侧黑色） |
| 5 | POS_ID | GND | 共地（一般为蓝色）|
| 6 | POS_GND | GND | 共地 |
---

## 3. ESP32-C3 引脚分配

| GPIO | 用途 | 接到哪 | 备注 |
|---|---|---|---|
| GPIO6 | TWAI_TX | `<CAN_IC>` 的 TXD | |
| GPIO7 | TWAI_RX | `<CAN_IC>` 的 RXD | |
| GPIO3 | I2C SDA | `<MPU_6050>` 的 SDA | |
| GPIO4 | I2C SCL | `<MPU_6050>` 的 SCL | |
| GPIO10 | 连接磁吸传感器母头检测其他传感器接入状态| `<>` | |

## 4. CAN 收发器接线（`<SN65HVD230>`）

| 收发器引脚 | 接到 |
|---|---|
| TXD | ESP32 GPIO6 |
| RXD | ESP32 GPIO7 |
| VCC | 3.3V 主电源轨 |
| GND | GND |
| CANH | 通过磁吸触点连接|
| CANL | 通过磁吸触点连接|

---

## 5. 传感器接线

| 传感器引脚 | 接到 | 备注 |
|---|---|---|
| VCC | 3.3V | |
| GND | GND | |
| SDA | ESP32 GPIO3 | 共用 I2C 总线 |
| SCL | ESP32 GPIO4 | 共用 I2C 总线 |
| INT | 悬空 | |
| AD0 | 悬空 | |

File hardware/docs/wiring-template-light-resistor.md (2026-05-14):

## 1. 模块概览
- **模块名称**：`module_light_resistor`
- **角色**：`<input module>`
- **传感器**：`<光敏电阻 (LDR, 常见型号 GL5528 / GL5537) + 10k 固定电阻>`
- **CAN 收发器**：`<SN65HVD230>`
- **6-pin 磁吸触点数量**：`<1 公>`（因为母头不够了）
---

## 2. 6-pin 磁吸触点定义

磁吸触点（公头）
| Pin # | 信号 | 说明 |
|---|---|---|---|
| 1 | VCC (3.3V) | 供电 (红色靠外)|
| 2 | GND| 共地（红色靠内）|
| 3 | CAN—H|  | （黄色） |
| 4 | CAN-L|  | （黄色右侧黑色） |
| 5 | POS_ID | GND | 共地（一般为蓝色）|
| 6 | POS_GND | GND | 共地 |
---

## 3. ESP32-C3 引脚分配

| GPIO | 用途 | 接到哪 | 备注 |
|---|---|---|---|
| GPIO6 | TWAI_TX | `<CAN_IC>` 的 TXD | |
| GPIO7 | TWAI_RX | `<CAN_IC>` 的 RXD | |
| GPIO0 | ADC1_CH0 | 分压器中点（LDR 与 10k 之间） | 模拟输入，0–3.3V |

## 4. CAN 收发器接线（`<SN65HVD230>`）

| 收发器引脚 | 接到 |
|---|---|
| TXD | ESP32 GPIO6 |
| RXD | ESP32 GPIO7 |
| VCC | 3.3V 主电源轨 |
| GND | GND |
| CANH | 通过磁吸触点连接|
| CANL | 通过磁吸触点连接|

---

## 5. 传感器接线

光敏电阻（LDR）阻值会随光强变化（亮 → 阻值小，暗 → 阻值大），跟一个 **10k 固定电阻** 串联组成**分压（voltage divider）**，中间节点喂到 ESP32-C3 的 ADC 引脚。

固件采用 **「亮 → 高电压」** 的接法：把 LDR 接在 3.3V 那一侧，10k 接在 GND 那一侧。

```
  3.3V ── LDR ──┬── GPIO0 (ADC1_CH0)
                │
              10k
                │
              GND
```

| 元件引脚 | 接到 | 备注 |
|---|---|---|
| LDR 一端 | 3.3V | 光敏电阻一端拉到电源 |
| LDR 另一端 + 10k 一端 | GPIO 0 | **ADC1_CH0** 模拟输入；中间节点电压随光强变化 |
| 10k 另一端 | GND | 10k 拉到地 |

**注意**：
- GPIO0 在 ESP32-C3 上是 ADC1_CH0，固件用 `analogRead(0)` 读取（默认 12-bit，0–4095），归一化成 0..1 后通过 `WB_CH_LIGHT (=41)` 发出。
- 如果你想反过来「暗 → 高电压」，把 LDR 和 10k 的位置交换即可，固件不需要改（只是语义反过来）。
- LDR 元件没有方向，两脚等价；但**整条分压一定要三段都接齐**：3.3V、ADC、GND 都要稳定连接，否则 ADC 读到的电压不可预期。
- 常见 GL5528 / GL5537 在室内大约 ~10k Ω，正好和这颗 10k 固定电阻匹配，分压中点会落在 ADC 量程的中段，留出向亮 / 向暗的双向余量。如果你的 LDR 在常态下阻值很大或很小，可以把 10k 换成接近常态阻值那一档来居中。

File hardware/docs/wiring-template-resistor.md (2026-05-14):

## 1. 模块概览
- **模块名称**：`module_resistor`
- **角色**：`<input module>`
- **传感器**：`<WH148 B100K>`，
- **CAN 收发器**：`<SN65HVD230>`
- **6-pin 磁吸触点数量**：`<1 公>`（因为母头不够了）
---

## 2. 6-pin 磁吸触点定义

磁吸触点（公头）
| Pin # | 信号 | 说明 |
|---|---|---|---|
| 1 | VCC (3.3V) | 供电 (红色靠外)|
| 2 | GND| 共地（红色靠内）|
| 3 | CAN—H|  | （黄色） |
| 4 | CAN-L|  | （黄色右侧黑色） |
| 5 | POS_ID | GND | 共地（一般为蓝色）|
| 6 | POS_GND | GND | 共地 |
---

## 3. ESP32-C3 引脚分配

| GPIO | 用途 | 接到哪 | 备注 |
|---|---|---|---|
| GPIO6 | TWAI_TX | `<CAN_IC>` 的 TXD | |
| GPIO7 | TWAI_RX | `<CAN_IC>` 的 RXD | |

## 4. CAN 收发器接线（`<SN65HVD230>`）

| 收发器引脚 | 接到 |
|---|---|
| TXD | ESP32 GPIO6 |
| RXD | ESP32 GPIO7 |
| VCC | 3.3V 主电源轨 |
| GND | GND |
| CANH | 通过磁吸触点连接|
| CANL | 通过磁吸触点连接|

---

## 5. 传感器接线

WH148 B100K 是一个三脚旋转电位器。按**分压（voltage divider）**接法：两端固定脚分别接 3.3V 和 GND，**中间的 wiper 脚**输出 0–3.3V 模拟电压，喂到 ESP32-C3 的 ADC 引脚。

| 旋钮引脚 | 接到 | 备注 |
|---|---|---|
| 端 1（固定脚 A） | 3.3V | 旋钮一端拉到电源 |
| 中（wiper） | GPIO 0 | **ADC1_CH0** 模拟输入；电压随旋钮位置在 0–3.3V 间变化 |
| 端 2（固定脚 B） | GND | 旋钮另一端拉到地 |

**注意**：
- GPIO0 在 ESP32-C3 上是 ADC1_CH0，固件用 `analogRead(0)` 读取（默认 12-bit，0–4095）。
- 三脚必须全部接好；只接 wiper + 一端会得到一个变化阻值，但不是分压，电压不可预期。
- 如��要省一根线做 demo，可以让 GND 共用 6-pin 触点的 GND，端 1 单独飞一根 3.3V。

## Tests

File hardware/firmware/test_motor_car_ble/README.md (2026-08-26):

# Motor Hub BLE Car Test

Standalone bring-up sketch for the two-motor `motor_hub` prototype. This folder is intentionally separate from the normal WearBlocks hub/module firmware.

Scope:

- Tests BLE control and two DRV8833 motor channels only.
- Does not initialize CAN.
- Does not scan the single magnetic face on GPIO0.

## Arduino IDE

1. Install ESP32 board support.
2. Install the `NimBLE-Arduino` library.
3. Open `test_motor_car_ble.ino`.
4. Select an ESP32-C3 board target.
5. Upload.

Recommended first power-up:

1. Keep the magnetic face empty.
2. Power the board and confirm serial output reaches `advertising as HexMotorCar`.
3. Connect from the test webpage.
4. Test at low speed before raising the slider.

BLE device name: `HexMotorCar`

Custom BLE service:

| UUID | Direction | Purpose |
|---|---|---|
| `6f8f0001-b5a3-f393-e0a9-e50e24dcca9e` | service | car test service |
| `6f8f0002-b5a3-f393-e0a9-e50e24dcca9e` | browser -> car | write commands |
| `6f8f0003-b5a3-f393-e0a9-e50e24dcca9e` | car -> browser | notify status |

Commands:

```text
D,<left>,<right>
S
B
P
```

`left` and `right` are signed speeds from `-255` to `255`.

## CLI Controller

The CLI connects through the computer's native BLE stack and does not require a
browser or Web Bluetooth. It discovers the car by service UUID, even when the
BLE advertisement does not contain a local name.

```bash
cd frontend/test_motor_car_ble
python3 -m venv .venv
.venv/bin/pip install -r requirements.txt
.venv/bin/python motor_car_cli.py
```

Controls:

| Key | Action |
|-----|---|
| `W` | Forward |
| `S` | Reverse |
| `A` / `D` | Turn left / right |
| `Space` | Coast stop |
| `B` | Brief brake, then stop |
| `+` / `-` | Increase / decrease speed |
| `P` | Request current motor status |
| `Q` | Stop, disconnect, and quit |

Use `--scan-only` to confirm that the BLE service is visible without connecting:

```bash
.venv/bin/python motor_car_cli.py --scan-only
```

Use `--address <BLE_IDENTIFIER>` to bypass scanning and connect directly. On
macOS the CoreBluetooth identifier is a UUID rather than a MAC address.

## Browser Test Frontend

Serve this repo directory from localhost and open:

```text
http://127.0.0.1:4173/index.html
```

The page is in:

```text
frontend/test_motor_car_ble/index.html
```

Web Bluetooth requires a secure context and a Chromium-based browser;
`localhost` / `127.0.0.1` satisfies the secure-context requirement. Firefox and
Safari do not expose Web Bluetooth, so use the CLI controller with those
browsers.

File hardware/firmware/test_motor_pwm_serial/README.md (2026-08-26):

# DRV8833 Serial PWM Test

Minimal two-motor bench test for the `motor_hub`. This sketch intentionally has
no BLE, CAN, face detection, car steering logic, heartbeat, or browser code.

## Wiring

| DRV8833 module | ESP32-C3 Super Mini |
|---|---|
| `IN1` | `GPIO1` |
| `IN2` | `GPIO2` |
| `IN3` | `GPIO3` |
| `IN4` | `GPIO4` |
| `GND` | Common GND |

`OUT1/OUT2` drive Motor 1 and `OUT3/OUT4` drive Motor 2. Supply the DRV8833
`VCC` from the motor supply in parallel with the Super Mini supply; do not route
motor current through the Super Mini. Keep all grounds connected.

## Serial Monitor

Flash `test_motor_pwm_serial.ino`, then open Arduino Serial Monitor with:

- Baud: `115200`
- Line ending: `Newline` or `Both NL & CR`

Alternatively, run the minimal serial CLI:

```bash
cd frontend/test_motor_pwm_serial
python3 -m venv .venv
.venv/bin/pip install -r requirements.txt
.venv/bin/python motor_pwm_cli.py
```

The CLI auto-detects a single `/dev/cu.usbmodem*` or
`/dev/cu.usbserial*` port. Pass a port path as its first argument when more than
one is connected. CLI shorthand: `120` controls both motors, `1 120` controls
Motor 1, `2 120` controls Motor 2, `s` stops, `p` prints status, and `q` sends
`STOP` before exiting.

Expected startup output:

```text
=== HexBlocks DRV8833 Serial PWM Test ===
PWM_ATTACH,GPIO1=ok,GPIO2=ok,GPIO3=ok,GPIO4=ok
STATUS,M1=0,M2=0,PWM=20000Hz,READY=yes
```

Commands:

```text
M1,120       Motor 1 forward at PWM 120/255
M1,-120      Motor 1 reverse at PWM 120/255
M2,120       Motor 2 forward at PWM 120/255
M2,-120      Motor 2 reverse at PWM 120/255
BOTH,120     Both motors at the same signed PWM
STOP         Stop both motors
STATUS       Print current commanded values
HELP         Print command help
```

## Test Order

Lift the wheels or disconnect the drivetrain before testing.

1. Send `STOP`.
2. Test Motor 1 at `M1,80`, `M1,120`, `M1,160`, and `M1,255`, stopping between values.
3. Send `STOP`, then repeat the same sequence with Motor 2.
4. Test reverse only after stopping: `M1,-160`, then `M2,-160`.
5. Send `STOP`, then test `BOTH,160`.

If both motors run at `255` but only one runs at a low value, the likely cause is
different motor starting thresholds rather than serial or PWM timing. If one
motor never runs, power off and swap the two motor output pairs:

- Failure follows the motor: inspect that motor, gearbox, and its wires.
- Failure stays on the same DRV8833 output pair: inspect that driver channel and
  its `IN1/IN2` or `IN3/IN4` wiring.

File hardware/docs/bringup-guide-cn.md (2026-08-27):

# WearBlocks 硬件联调测试指南

适用范围：当前 `main` 分支的固件（hub: ESP32-C3-MINI-1，digital PosID）+ 任意一种或多种模块。本指南按"先 hub smoke test，再逐模块单插验证，再热插拔/堆叠"的顺序组织，不再绑定到某一种模块。

---

## 0. 准备工作

### 0.1 烧录 hub 固件

| 板子 | sketch 路径 | 目标芯片 |
|---|---|---|
| 有线 Hub（默认） | `hardware/firmware/hub/hub.ino` | ESP32-C3-MINI-1 |
| Wi-Fi/OSC Hub | `hardware/firmware/wifi_hub/wifi_hub.ino` | ESP32-C3-MINI-1 |

烧录前安装的 lib：把 `hardware/firmware/lib/` 下的 `WearBlocksCAN`、`WearBlocksProtocol`、`WearBlocksDescriptor`、`WearBlocksModule`、`WearBlocksECA`、`WearBlocksPosID`、`WearBlocksTransport` 软链或拷到 Arduino libraries 目录。只有 `wifi_hub` 和支持无线回退的模块还需要 `WearBlocksWireless`。

### 0.2 烧录模块固件

每个模块是一块 ESP32-C3-MINI-1。Sketch 路径：

| 模块 | Sketch 路径 | 颜色 (canvas) | 主要传感/执行器 |
|---|---|---|---|
| 6-Axis IMU | `hardware/firmware/module_imu/module_imu.ino` | `#7CA1BB` 灰蓝 | MPU6050 |
| RGB LED | `hardware/firmware/module_led/module_led.ino` | `#C68E9E` 玫粉 | WS2812B ring |
| Vibration | `hardware/firmware/module_vibration/module_vibration.ino` | `#50C878` 海绿 | DRV2605L + ERM |
| Audio Synth | `hardware/firmware/module_amplifier/module_amplifier.ino` | `#9885BF` 紫 | MAX98357A + 8Ω |
| Light Sensor | `hardware/firmware/module_light_resistor/module_light_resistor.ino` | `#C1B496` 米色 | GL5528 LDR |
| Rotary Knob | `hardware/firmware/module_resistor/module_resistor.ino` | `#98AF6F` 橄榄绿 | WH148 B100K |

> 同一种模块的多个实例不需要改 slot 号——slot 由 hub 在 `$H` 之后动态分配。但同一个 UID 不能上线两次。每块板子的 UID 来自 efuse MAC，天然唯一。

**C3 烧录常见坑**：

- **GPIO 2、8、9 是 strap pin**。如果板子烧完按 RESET 起不来，多半是某个 child-detect / face pin 上电时被外部硬拉到 GND 或 3.3V。先把可疑外设拔掉再 RESET。
- **MPU6050 等 I2C 外设接错**会让 `*.begin()` 挂住但不报错。先单独跑 `Wire.begin(); Wire.beginTransmission(0x68);` 之类的最小代码确认 ACK。

### 0.3 安装 bridge 依赖

```bash
cd frontend/bridge
pip install -r requirements.txt
```

### 0.4 列举串口

```bash
python3 frontend/tools/wb_debug.py --list
```

记下 hub 的 port（macOS 形如 `/dev/cu.usbmodem...`，Linux 形如 `/dev/ttyACM0`）。模块板子不需要接电脑，只要 CAN 和电源（USB 给 hub 供电时，模块通过 pogo 共享 3.3V 即可）。

---

## 1. Smoke test：只接 hub

不插任何模块，先单独看 hub 自己起得来。

```bash
python3 frontend/tools/wb_debug.py --port /dev/cu.usbmodemXXX
```

期望输出（关键几行）：

```
=== WearBlocks Hub — Digital PosID ===
[OK] CAN: TX=GPIO6 RX=GPIO7 @500kbps
[OK] Face pins: F1=GPIO0  F2=GPIO2  F3=GPIO3  F4=GPIO4  F5=GPIO8  F6=GPIO10
  F1 initial: empty
  F2 initial: empty
  F3 initial: empty
  F4 initial: empty
  F5 initial: empty
  F6 initial: empty
[WAIT] Listening for module HELLO ...
```

按 `s` 键 → 期望立刻收到 `$Q DONE`（registry 为空）。按 `t` 键 → `=== TOPOLOGY === HUB 0 module(s) registered === END ===`。

**如果某个 face 初始显示 `OCCUPIED` 但其实没接东西**——对应 GPIO 被悬空/拉低了，是硬件问题。查 PCB 走线或外接 pull-up 验证。

---

## 2. 单模块插入：每种模块的期望事件

通用流程：
1. 启动 bridge 和前端：`python3 frontend/bridge/serial_bridge.py /dev/cu.usbmodemXXX`
2. 浏览器打开 `http://localhost:3000`，可选按 `Ctrl/Cmd + D` 打开调试面板。
3. 把模块插到 hub 的某一面（任意面均可），观察日志和 canvas。

### 2.1 通用 `$H` 行格式

```
$H,<uid_hex>,<moduleId>,HUB,<face>
```

- `<uid_hex>`：8 位十六进制，由模块 efuse MAC 派生
- `<moduleId>`：descriptor.moduleId 字段。除 vibration 写死为 `vib_v2` 外，其他模块都是 `<category>_<uid>`（IMU 是 `imu_<uid>`，LED 是 `led_<uid>`，依此类推）。
- 紧接着 hub 会发 `[DESC] requesting slot N descriptor`，模块回 `$D ...`，hub 回 `$OK`。
- canvas 上对应 face 出现一个对应颜色的六边形。

### 2.2 各模块期望

| 模块 | 期望 `$H` 关键字段 | 期望 `$S` 频率（直接看不到，但 debug panel 会显示 rate） | canvas 颜色 |
|---|---|---|---|
| IMU | moduleId=`imu_<uid>` | 6 raw 通道默认 50 Hz → ~300 frame/s；启用 ACC_MAG/PITCH 后翻倍 | 灰蓝 `#7CA1BB` |
| LED | moduleId=`led_<uid>` | 0/s（执行器，不主动报） | 玫粉 `#C68E9E` |
| Vibration | moduleId=`vib_v2` | 0/s | 海绿 `#50C878` |
| Audio Synth | moduleId=`audio_<uid>` | 0/s | 紫 `#9885BF` |
| Light Sensor | moduleId=`light_<uid>` | 单通道 ~10–20 Hz | 米色 `#C1B496` |
| Rotary Knob | moduleId=`knob_<uid>` | 仅在转���时上报，最高 50 Hz；静止时为 0 | 橄榄绿 `#98AF6F` |

### 2.3 验证执行器（LED / Vibration / Audio）

执行器模块插入后默认不会主动产出 `$S`。最快的"它真的在线"测试是从 Blockly 写一条 ECA 规则触发它，或在调试面板里手动发一条：

- **LED**: 拖一个 "always" → "set color" 块，颜色任选。期望模块上的 NeoPixel 立刻亮。
- **Vibration**: "always" → "vibrate, 200ms"。模块上的 ERM 短促一震。
- **Audio Synth**: "always" → "play tone 440Hz"。喇叭出 1 声 A4。

如果在 canvas 上看到模块但执行没反应，9 成是这一面的 pogo 没接通 GND/3.3V——晃一晃模块再试。

---

## 3. 热插拔验证

任意一种模块都适用。流程和期望：

| 操作 | 期望 CLI | 期望 UI |
|---|---|---|
| 拔掉模块 | 100 ms 后：`$X slot N from F<face> (pending)`；7 s 后：`✕ UNPLUG slot N` | 拔的瞬间六边形变淡 35%（ghost），7 s 后消失 |
| 拔掉后 5 s 内换面插回 | `$X slot N from F<old> (pending)` 然后 `↔ HOT-SWAP slot N: F<old> → F<new>` | Ghost 变回实色，六边形从旧面跳到新面；slot 号不变 |
| 同时插两个模块 | 两组 `[DESC] requesting slot N descriptor` **串行** 出现，不会交错 | 两个六边形依次出现 |
| 浏览器按 ↻（resync） | bridge → 串口发 `$Q,STATUS`；hub 回所有 `$H`+`$D` 然后 `$Q DONE` | canvas 保持稳定，不闪烁 |

---

## 4. 堆叠（CHILD_EVENT）

任何 down-half 面上有 PosID GND 打脚的模块都能承载子模块。当前 IMU、LED、Vibration、Amplifier 的 `module_*.ino` 里都定义了 `CHILD_PINS[]`（一般是 face 4/5/6 → GPIO 2/8/10），意思是这三个面在物理上做了 down-half pogo。

### 4.1 物理拓扑（以 hub → IMU-A → IMU-B 为例）

```
    ┌──────────┐
    │   HUB    │
    └────┬─────┘
         │  F1
    ┌────┴──────┐
    │  IMU-A    │   ← slot 1，直连 hub F1
    │  (up F1,  │
    │   dn F4)  │   ← down-half face 4 是子模块挂载位
    └────┬──────┘
         │
    ┌────┴──────┐
    │  IMU-B    │   ← slot 2，堆在 IMU-A 的 F4 上
    └───────────┘
```

### 4.2 期望事件序列

**阶段 1：先插 IMU-A 到 hub F1**——同 §2 单模块流程，hub 给它发 `$H,...,HUB,1`。

**阶段 2：把 IMU-B 堆到 IMU-A 的 F4 上**——IMU-A 上电后周期检测 child detect pin，发现 F4 被拉低，发 `CHILD_EVENT` 给 hub。期望日志：

```
[CHILD] slot 1 face 4 OCCUPIED → child-side
$H,<uid_B>,imu_<uid_B>,SLOT 1,4
[DESC] requesting slot 2 descriptor
$D ...
$OK ...
```

注意 `$H` 的第三个字段从 `HUB` 变成 `SLOT 1`——表示父节点是 slot 1 而不是 hub。canvas 上 IMU-B 渲染在 IMU-A 的 F4 方向上。

**阶段 3：拔 IMU-B**——slot 2 走 §3 的热插拔逻辑；IMU-A（slot 1）不动。

---

## 5. 常见坑速查

| 现象 | 多半原因 |
|---|---|
| Hub 起来但所有 face 都 `OCCUPIED` | face pin 全被外部下拉。检查 PCB 走线或临时把 pull-up 改成 33k 试试。|
| 模块插上去 hub 没有 `$H` | (a) CAN 接反 / 没接 120Ω 终端；(b) 模块烧错了 sketch；(c) 模块那一面的 GND pogo 没接通。先用万用表量 CAN_H/CAN_L 静态电压（应在 ~2.5V）。|
| `$D` parse 失败（`[DESC] slot N: parse failed`） | 描述字段超长（name > 32, category > 32, color > 8）或字符串没 null-terminate。`strlcpy` 的第三个参数对了吗？|
| 数���率极低（<10/s 而期望 300） | `WBModule.tick()` 没在 `loop()` 里调用，或 `sendChannel()` 被 topic gating 卡住。debug panel 里手动 enable 一下相关通道。|
| LED / Vibration 在线但执行无响应 | 执行器供电 pogo 没接通；或者 actuator command id 写错（IDs 见各 sketch 头部注���）。|
| 堆叠后子模块的 `$H` 不出现 | 父模块这一面没在 `CHILD_PINS[]` 里登记，或登记的 GPIO 跟实际 PCB 不一致。|

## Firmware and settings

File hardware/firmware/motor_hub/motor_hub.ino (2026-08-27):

/*
 * WearBlocks Motor Hub v1 — one-face hub + built-in DRV8410 motors
 * Target: ESP32-C3FH4
 *
 * Architecture:
 *   - CAN bus master (500 kbps).
 *   - Digital presence: 6 GPIOs as INPUT_PULLUP, one per hub face. Module's
 *     dock ties POS_ID to GND → digitalRead == LOW means occupied.
 *     Debounced 5 × 20 ms.
 *   - Identity: each module sends its UID (efuse MAC low 32 bits) in HELLO.
 *     UID is the canonical key for *everything* visible outside this process.
 *     slot (1..11) is an internal CAN addressing alias, kept persistent for
 *     the UID's lifetime in the registry.
 *   - Single truth source per fact:
 *       • hub-face occupancy       ← hub FACE_PIN debounce
 *       • module-R-face occupancy  ← that module's CHILD_EVENT
 *       • module identity          ← HELLO.uid
 *       • module's parent+face     ← derived by hub from a FIFO queue of
 *                                    pending attach signals (HUB_FACE_OCC or
 *                                    MODULE_CHILD_OCC). No inference spread
 *                                    across multiple callbacks.
 *   - TTL: a module going physically absent is marked DETACHED; slot held
 *     8 s before reap. Reinsertion within 8 s preserves slot and — if
 *     fwHash matches cache — skips descriptor transfer entirely.
 *   - Stacking depth: supports arbitrary parent-slot chains (3+ layers).
 *
 * Serial bridge line protocol (UID-keyed; slot never leaked to frontend):
 *   $H,<uid>,<moduleId>,<parentUid|HUB>,<parentFace>
 *       module registered/re-registered; moduleId may be "" pending descriptor
 *   $D,<uid>,<descriptorJSON>
 *   $I,<uid>,<moduleId>,<version>,<fwHash>
 *       identity/version note; moduleId/version may be "" pending descriptor
 *   $S,<uid>,<channelId>,<floatValue>
 *   $X,<uid>                                detached (TTL started)
 *   $F,<uid>,<oldParent>,<oldFace>,<newParent>,<newFace>  moved/rebound
 *   $U,<uid>                                unplugged (TTL fired or evicted)
 *   $C,<parentUid>,<childUid|PENDING>,<parentFace>        child docked
 *   $c,<parentUid>,<childUid|PENDING>,<parentFace>        child undocked
 *   $T,<uid>,<parentUid|HUB>,<parentFace>                 topology entry
 *   $Q,DONE                                               end of resync
 *
 * Host commands (Serial → hub):
 *   $Q,STATUS              dump current registry as $H/$D lines + $Q,DONE
 *   $Q,TOPO                emit $T,<uid>,<parent>,<face> for each module
 *   $Q,ECA                 emit $E summary + $EB raw bytecode (if loaded) + $Q,DONE
 *   $Q,FORGET ALL          wipe topology memory (use before offline rearrange)
 *   $Q,FORGET <uidHex>     wipe one remembered binding
 *   $P <base64>            upload + auto-run ECA bytecode (also persists to NVS)
 *   $PR / $PS / $PC        run / stop / clear ECA ($PC also wipes NVS)
 *   $PE                    erase persisted ECA bytecode from NVS only (runtime untouched)
 *   $A <uidHex> <cmd> <p...>  actuator EXECUTE
 *   $TE <uidHex> <ch>      topic enable;  $TD <uidHex> <ch> disable
 *   $TA <uidHex>           topic enable all
 */

#include <WearBlocksCAN.h>
#include <WearBlocksProtocol.h>
#include <WearBlocksDescriptor.h>
#include <WearBlocksECA.h>
#include <Preferences.h>
#include <mbedtls/base64.h>
#include "ModuleRegistry.h"

#if __has_include(<esp_arduino_version.h>)
#include <esp_arduino_version.h>
#endif
#ifndef ESP_ARDUINO_VERSION_MAJOR
#define ESP_ARDUINO_VERSION_MAJOR 2
#endif

// ── BLE peripheral ────────────────────────────────���───────────
// The hub exposes Nordic UART Service so the bridge (`bleak`) can read
// the same $-prefixed protocol stream that USB-CDC carries. USB and BLE
// are mutually exclusive at the bridge layer; the firmware keeps both
// alive at the same time and lets whichever side has a live host write
// commands. No PIN/bonding — Just-Works pairing only (lab use).
//
// arduino-esp32 v3+ ships NimBLE-Arduino as the recommended stack on
// ESP32-C3. If your toolchain pulls the older Bluedroid `BLEDevice.h`,
// swap the include line and replace NimBLE classes with their BLE*
// counterparts (the API surface used here is intentionally small).
#include <NimBLEDevice.h>

#define NUS_SERVICE_UUID  "6E400001-B5A3-F393-E0A9-E50E24DCCA9E"
#define NUS_RX_CHAR_UUID  "6E400002-B5A3-F393-E0A9-E50E24DCCA9E"  // host -> hub
#define NUS_TX_CHAR_UUID  "6E400003-B5A3-F393-E0A9-E50E24DCCA9E"  // hub  -> host

NimBLECharacteristic* g_bleTxChar       = nullptr;
NimBLECharacteristic* g_bleRxChar       = nullptr;
volatile bool         g_bleClientConnected = false;
char                  g_bleAdvName[16] = {0};

// Forward declaration (used by MirrorStream below).
static void bleNotifyLine(const char* line, size_t len);

// MirrorStream — Print subclass that line-buffers output, writes each
// byte to USB Serial, and flushes whole '\n'-terminated lines to BLE
// notify when a client is connected. Used only at $-protocol emission
// sites; debug `[XXX]` messages keep using `Serial` directly so they
// don't pollute the BLE channel.
class MirrorStream : public Print {
public:
    char   _buf[512];
    size_t _len = 0;

    size_t write(uint8_t c) override {
        Serial.write(c);
        _accumulate(c);
        return 1;
    }
    size_t write(const uint8_t* data, size_t size) override {
        size_t n = Serial.write(data, size);
        for (size_t i = 0; i < size; i++) _accumulate(data[i]);
        return n;
    }

private:
    void _accumulate(uint8_t c) {
        if (_len < sizeof(_buf) - 1) _buf[_len++] = (char)c;
        // BLE may need to carry long protocol lines such as `$EB,<base64>`.
        // Flush full fragments too; the bridge reassembles notify chunks
        // until it sees the final newline.
        if (c == '\n' || _len == sizeof(_buf) - 1) {
            _buf[_len] = '\0';
            bleNotifyLine(_buf, _len);
            _len = 0;
        }
    }
};

MirrorStream out;
static char g_hostActuatorRequestId[65] = {0};
static void emitActuatorState(uint32_t uid, uint8_t cmd,
                              const uint8_t* params, uint8_t paramLen);

// ── Pin assignment ─────────────────────────────────────────────
#define CAN_TX_PIN   7
#define CAN_RX_PIN   6
#define STATUS_LED   9

static const uint8_t FACE_COUNT = 1;
static const uint8_t FACE_PIN = 5;
static const uint8_t MOTOR1_IN1_PIN = 0;
static const uint8_t MOTOR1_IN2_PIN = 1;
static const uint8_t MOTOR2_IN1_PIN = 3;
static const uint8_t MOTOR2_IN2_PIN = 4;
static const uint8_t MOTOR_SLEEP_PIN = 10;
static const uint32_t PWM_FREQ_HZ = 20000;
static const uint8_t PWM_BITS = 8;
static const uint8_t CH_M1_IN1 = 0;
static const uint8_t CH_M1_IN2 = 1;
static const uint8_t CH_M2_IN1 = 2;
static const uint8_t CH_M2_IN2 = 3;

WearBlocksCAN      can;
WearBlocksProtocol protocol;
ModuleRegistry     registry;
WearBlocksECA      eca;
WearBlocksDescriptor builtinMotorDescriptor;
uint32_t builtinMotorUid = 0;

enum MotorMode : uint8_t {
    MOTOR_STOP = 0,
    MOTOR_FORWARD = 1,
    MOTOR_REVERSE = 2,
};

struct MotorState {
    uint8_t mode;
    uint8_t speed;
    uint32_t untilMs;
};

MotorState motors[2] = {{MOTOR_STOP, 0, 0}, {MOTOR_STOP, 0, 0}};

static void writePwm(uint8_t pin, uint8_t channel, uint8_t duty) {
#if ESP_ARDUINO_VERSION_MAJOR >= 3
    (void)channel;
    ledcWrite(pin, duty);
#else
    (void)pin;
    ledcWrite(channel, duty);
#endif
}

static bool attachPwm(uint8_t pin, uint8_t channel) {
#if ESP_ARDUINO_VERSION_MAJOR >= 3
    (void)channel;
    bool ok = ledcAttach(pin, PWM_FREQ_HZ, PWM_BITS);
#else
    double actual = ledcSetup(channel, PWM_FREQ_HZ, PWM_BITS);
    ledcAttachPin(pin, channel);
    bool ok = actual > 0;
#endif
    if (ok) writePwm(pin, channel, 0);
    return ok;
}

static void applyMotorOutputs(uint8_t index) {
    const MotorState& state = motors[index];
    const bool first = index == 0;
    const uint8_t in1 = first ? MOTOR1_IN1_PIN : MOTOR2_IN1_PIN;
    const uint8_t in2 = first ? MOTOR1_IN2_PIN : MOTOR2_IN2_PIN;
    const uint8_t ch1 = first ? CH_M1_IN1 : CH_M2_IN1;
    const uint8_t ch2 = first ? CH_M1_IN2 : CH_M2_IN2;

    if (state.mode == MOTOR_FORWARD && state.speed > 0) {
        writePwm(in1, ch1, state.speed);
        writePwm(in2, ch2, 0);
    } else if (state.mode == MOTOR_REVERSE && state.speed > 0) {
        writePwm(in1, ch1, 0);
        writePwm(in2, ch2, state.speed);
    } else {
        writePwm(in1, ch1, 0);
        writePwm(in2, ch2, 0);
    }
}

static void setMotor(uint8_t motor, uint8_t mode, uint8_t speed,
                     uint16_t durationMs) {
    if (motor < 1 || motor > 2 || mode > MOTOR_REVERSE) return;
    const uint8_t index = motor - 1;
    MotorState& state = motors[index];
    if (mode == MOTOR_STOP || speed == 0) {
        state = {MOTOR_STOP, 0, 0};
    } else {
        state.mode = mode;
        state.speed = speed;
        state.untilMs = durationMs > 0 ? millis() + durationMs : 0;
    }
    applyMotorOutputs(index);
    Serial.printf("[MOTOR] local M%d mode=%d speed=%d duration=%u\n",
                  motor, state.mode, state.speed, durationMs);
}

static bool handleLocalActuator(uint32_t targetUid, uint8_t cmd,
                                const uint8_t* payload, uint8_t payloadLen) {
    if (targetUid != builtinMotorUid || cmd != ACT_MOTOR_SET) return false;
    if (!payload || payloadLen < 5) return true;
    const uint16_t durationMs = ((uint16_t)payload[3] << 8) | payload[4];
    setMotor(payload[0], payload[1], payload[2], durationMs);
    emitActuatorState(targetUid, cmd, payload, payloadLen);
    return true;
}

static void tickMotors() {
    const uint32_t now = millis();
    for (uint8_t i = 0; i < 2; i++) {
        if (motors[i].untilMs != 0 &&
            (int32_t)(now - motors[i].untilMs) >= 0) {
            motors[i] = {MOTOR_STOP, 0, 0};
            applyMotorOutputs(i);
            Serial.printf("[MOTOR] local M%d duration complete\n", i + 1);
        }
    }
}

static void setupBuiltinMotorDescriptor() {
    // moduleId is a type label (16-byte field); UID carries instance identity.
    strlcpy(builtinMotorDescriptor.moduleId, "motor_builtin",
            sizeof(builtinMotorDescriptor.moduleId));
    strlcpy(builtinMotorDescriptor.name, "Built-in Dual Motor",
            sizeof(builtinMotorDescriptor.name));
    strlcpy(builtinMotorDescriptor.category, "motor_output",
            sizeof(builtinMotorDescriptor.category));
    strlcpy(builtinMotorDescriptor.color, "#D97757",
            sizeof(builtinMotorDescriptor.color));
    strlcpy(builtinMotorDescriptor.version, "1.0",
            sizeof(builtinMotorDescriptor.version));

    builtinMotorDescriptor.numCapabilities = 1;
    WBCapability& motor = builtinMotorDescriptor.capabilities[0];
    strlcpy(motor.type, "actuator", sizeof(motor.type));
    strlcpy(motor.modality, "dual_motor", sizeof(motor.modality));
    motor.axes = 2;
    motor.rangeMin = -255.0f;
    motor.rangeMax = 255.0f;
    motor.resolution = 1.0f;
    strlcpy(motor.dataType, "int16[2]", sizeof(motor.dataType));
    motor.numSampleRates = 0;
    builtinMotorDescriptor.numAffordances = 2;
    strlcpy(builtinMotorDescriptor.affordances[0], "independent_motor_control",
            sizeof(builtinMotorDescriptor.affordances[0]));
    strlcpy(builtinMotorDescriptor.affordances[1], "built_in",
            sizeof(builtinMotorDescriptor.affordances[1]));
}

// ── Tunables ──────────────────────────────────────────────────
const uint32_t FACE_SCAN_TICK         = 20;
const uint8_t  DEBOUNCE_CONSECUTIVE   = 5;
const uint32_t DETACH_TTL_MS          = 8000;
// Pending attach TTL was 5000 ms originally. Pulled to 12000 so a single
// CAN packet loss won't expire an attach before the module's next HELLO
// retry / keepalive lands. With B8's hub-face keepalive re-enqueueing
// every 4s on still-occupied faces, the actual time an attach can be
// stale is bounded by HUB_FACE_KEEPALIVE_MS, not this TTL — but the
// extra slack helps debug prints stay coherent under load.
const uint32_t PENDING_ATTACH_TTL_MS  = 12000;
// Hub-face attach keepalive. Mirrors what modules already do for their
// own child faces (CHILD_KEEPALIVE_MS in module_imu): every 4s, every
// committed-occupied hub face re-enqueues an ATTACH_HUB_FACE entry
// (enqueueAttach dedups + refreshes timestamp on existing entries). This
// is what makes "hub reboots while modules stay powered" recoverable: a
// module's 7s keepalive HELLO finds a fresh attach in the queue and
// takes the unknown-UID first-time-insertion path. Also recovers a
// face whose PENDING module was reaped after descriptor handshake
// failure — the face stays occupied so the keepalive keeps the attach
// fresh until the module retries HELLO.
const uint32_t HUB_FACE_KEEPALIVE_MS  = 4000;
const uint32_t STATS_INTERVAL         = 5000;

// ── Face debounce ─────────────────────────────────────────────
struct FaceTrack {
    bool     committedOccupied;
    uint8_t  streak;
};
FaceTrack faceTracks[FACE_COUNT] = {};
uint32_t  lastFaceScan = 0;

// ── Pending-attach FIFO ───────────────────────────────────────
// A unified queue of "somebody just appeared at this parent.face" signals.
// Entries come from:
//   HUB_FACE:     hub's own GPIO debounce fires occupied
//   MODULE_CHILD: a registered module reports CHILD_EVENT(occupied=1)
// HELLO consumes the oldest unconsumed entry within PENDING_ATTACH_TTL_MS;
// that entry tells us the new module's parent slot + face.
//
// If a face/child event goes unoccupied while its entry is still pending,
// that entry is pruned (the module that was physically present left before
// sending HELLO — a transient that should not later match a different UID).
enum AttachKind : uint8_t { ATTACH_HUB_FACE, ATTACH_MODULE_CHILD };
struct PendingAttach {
    bool       active;
    AttachKind kind;
    uint8_t    hubFace;        // kind == HUB_FACE
    uint8_t    parentSlot;     // kind == MODULE_CHILD
    uint8_t    parentFace;     // kind == MODULE_CHILD
    uint32_t   createdAtMs;
};
// Explicit prototypes keep Arduino's .ino preprocessor from placing these
// declarations before AttachKind is defined.
void enqueueAttach(AttachKind k, uint8_t hubFace,
                   uint8_t parentSlot, uint8_t parentFace);
void pruneAttach(AttachKind k, uint8_t hubFace,
                 uint8_t parentSlot, uint8_t parentFace);
#define PENDING_ATTACH_MAX 16
PendingAttach attachQueue[PENDING_ATTACH_MAX] = {};

// ── UID-keyed topology memory (NVS-backed) ────────────────────
// What it solves:
//   Hub-only reboot with multiple modules still powered. Setup() enqueues
//   every occupied face essentially simultaneously, so the FIFO pick has
//   no information to tell module-A's HELLO apart from module-B's. The
//   wrong binding is *stable* — keepalive HELLOs from a registered UID
//   are idempotent, so the misbinding never self-corrects.
//
// How it works:
//   Each successful registration writes (uid, parentUid, parentFace) into
//   an in-memory table mirrored to NVS (Preferences blob). On reboot the
//   table is loaded; when an unknown UID's HELLO arrives, the hub checks
//   the table first. If memory has a remembered binding AND the
//   remembered face is still physically occupied AND the parent (HUB or
//   another module by UID) is currently registered, the hub binds to the
//   remembered location instead of consuming a FIFO attach. memory miss
//   falls back to the FIFO + ambiguous log path.
//
// Persistence policy:
//   Mutations set _topoDirty; loop() flushes once every 30s if dirty.
//   This bounds NVS wear at well under one write per minute even under
//   continuous reseat. Memory loss in the 30s window since the last
//   flush degrades to FIFO behavior, which is acceptable.
struct TopologyMemoryEntry {
    uint32_t uid;          // 0 == empty slot
    uint32_t parentUid;    // 0 == HUB
    uint8_t  parentFace;   // 1..6
    uint8_t  reserved[3];  // pad to 12 bytes for stable on-disk layout
};
static TopologyMemoryEntry* findTopoEntry(uint32_t uid);
#define TOPO_MEM_MAX WB_MAX_MODULES   // 12 entries × 12 B = 144 B blob
TopologyMemoryEntry topoMemory[TOPO_MEM_MAX] = {};
bool      topoDirty       = false;
uint32_t  topoLastFlushMs = 0;
const uint32_t TOPO_FLUSH_MS = 30000;
static const char* TOPO_NVS_NS  = "wb-topo";
static const char* TOPO_NVS_KEY = "mem";

static TopologyMemoryEntry* findTopoEntry(uint32_t uid) {
    if (uid == 0) return nullptr;
    for (uint8_t i = 0; i < TOPO_MEM_MAX; i++) {
        if (topoMemory[i].uid == uid) return &topoMemory[i];
    }
    return nullptr;
}
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
void loop() {
    processSerialCommands();
    processBleCommands();
    protocol.processIncoming();
    eca.tick();
    tickMotors();

    uint32_t now = millis();

    // Round-robin one face per tick (6 faces in 120 ms).
    if (now - lastFaceScan >= FACE_SCAN_TICK) {
        lastFaceScan = now;
        static uint8_t cursor = 0;
        bool occ = (digitalRead(FACE_PIN) == LOW);
        trackFaceSample(cursor + 1, occ);
        cursor = (cursor + 1) % FACE_COUNT;
    }

    registry.reapDetached(now, DETACH_TTL_MS, onSlotRemoved);
    reapAttachQueue(now);

    // Throttled flush of topology memory to NVS. Mutations only set
    // topoDirty; this is the single point that actually writes flash,
    // bounding wear at one write per TOPO_FLUSH_MS even under continuous
    // reseat. A hub crash within the window forfeits the most recent
    // bindings, which degrades to FIFO behavior.
    if (topoDirty && now - topoLastFlushMs >= TOPO_FLUSH_MS) {
        topoLastFlushMs = now;
        if (saveTopoMemory()) {
            topoDirty = false;
            Serial.println("[TOPO] flushed memory to NVS");
        }
    }

    // Hub-face attach keepalive. Re-enqueue an ATTACH_HUB_FACE entry for
    // every committed-occupied hub face that does NOT currently hold a
    // REGISTERED module. enqueueAttach dedups by (kind, hubFace) and
    // refreshes the timestamp on the existing entry, so this is cheap.
    // Without this, two failure modes break "hub reboots, modules stay
    // powered":
    //   1. After hub reboot, setup() enqueues each occupied face exactly
    //      once. PENDING_ATTACH_TTL_MS expires before the module's next
    //      7s keepalive HELLO, so the HELLO becomes orphan-dropped.
    //   2. After PENDING reap (descriptor handshake failed 10x), the
    //      face stays occupied — no new GPIO edge — but the registry
    //      entry is gone. Without re-enqueue, the next HELLO is orphan.
    //
    // Skipping REGISTERED-occupied faces is critical: otherwise a stale
    // attach for an already-bound face sits at the head of the FIFO and
    // blocks every other module's unknown HELLO from finding its real
    // attach (head-of-line blocking, made worse by attach-kept-on-fail).
    // PENDING / DETACHED occupants don't block — those modules may have
    // gone away and the face is genuinely available for re-binding.
    static uint32_t lastFaceKeepalive = 0;
    if (now - lastFaceKeepalive >= HUB_FACE_KEEPALIVE_MS) {
        lastFaceKeepalive = now;
        for (uint8_t f = 0; f < FACE_COUNT; f++) {
            if (!faceTracks[f].committedOccupied) continue;
            uint8_t occ = registry.findChildSlot(WB_PARENT_HUB, f + 1);
            if (occ != 0xFF) {
                const RegisteredModule* m = registry.getModule(occ);
                if (m && m->state == MODULE_REGISTERED) continue;
            }
            enqueueAttach(ATTACH_HUB_FACE, f + 1, 0, 0);
        }
    }

    // Re-poke any module stuck in PENDING. If the original descriptor
    // request or the module's reply was lost on the bus, retry every
    // PENDING_RETRY_MS — but bail after PENDING_RETRY_MAX so a wedged
    // module doesn't squat on a slot forever. removeSubtree fires
    // onPendingSlotRemoved → $U so the frontend stops showing the ghost
    // while keeping topology memory for the module's next HELLO.
    static uint32_t lastPendingScan = 0;
    const uint32_t PENDING_RETRY_MS  = 2000;
    const uint8_t  PENDING_RETRY_MAX = 10;   // ~20s at 2s cadence
    if (now - lastPendingScan >= PENDING_RETRY_MS) {
        lastPendingScan = now;
        for (uint8_t i = 1; i < WB_MAX_MODULES; i++) {
            const RegisteredModule* m = registry.getModule(i);
            if (!m || m->state != MODULE_PENDING) continue;
            uint8_t tries = registry.bumpPendingRetries(i);
            if (tries >= PENDING_RETRY_MAX) {
                Serial.printf("[REG] giving up on PENDING slot=%d uid=%08lX (%d retries)\n",
                              i, (unsigned long)m->uid, tries);
                registry.removeSubtree(i, onPendingSlotRemoved);
            } else {
                Serial.printf("[REG] retry descriptor: slot=%d uid=%08lX try=%d\n",
                              i, (unsigned long)m->uid, tries);
                protocol.requestDescriptor(i);
            }
        }
    }

    if (now - statsStart >= STATS_INTERVAL) {
        if (registry.getModuleCount() > 0) {
            float elapsed = (now - statsStart) / 1000.0f;
            float hz = (elapsed > 0) ? sampleCount / elapsed : 0;
            Serial.printf("[STATS] samples=%lu %.1fHz modules=%d\n",
                          sampleCount, hz, registry.getModuleCount());
        }
        sampleCount = 0;
        statsStart = now;
    }

    protocol.sendHeartbeat();
    delay(1);
}

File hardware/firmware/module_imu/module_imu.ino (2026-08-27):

/*
 * WearBlocks Module — 6-Axis IMU (Slate #7CA1BB)
 * Target: ESP32-C3-MINI-1
 * Sensor: MPU6050 (GY-521 breakout)
 *
 * Internally this is the v3 sketch: registration boilerplate (UID derive,
 * fwHash, onAck, onDescriptorRequested, HELLO retry) lives in the shared
 * WearBlocksModule library so it can be reused by LED/vibration/etc.
 * This sketch is the reference user of that lib.
 *
 * Channels published over CAN (single-channel frames):
 *   Raw (always ON):        AX, AY, AZ, GX, GY, GZ
 *   Derived (topic-gated):  ACC_MAG, GYRO_MAG, PITCH, ROLL,
 *                           AX_LPF, AY_LPF, AZ_LPF, ACC_MAG_LPF, JERK
 *   Events (topic-gated):   SHAKE, STEP, FREEFALL
 */

#include <WearBlocksCAN.h>
#include <WearBlocksProtocol.h>
#include <WearBlocksDescriptor.h>
#include <WearBlocksModule.h>
#include <WearBlocksWireless.h>
#include <WearBlocksECA.h>
#include <Wire.h>
#include <MPU6050_light.h>
#include <math.h>

// ── Pin assignment (ESP32-C3-MINI-1) ──────────────────────────
#define CAN_TX     6
#define CAN_RX     7
#define I2C_SDA    3
#define I2C_SCL    4

#ifndef CHILD_DETECT
#define CHILD_DETECT 1
#endif

#if CHILD_DETECT
struct ChildFacePin { uint8_t face; uint8_t gpio; };
const ChildFacePin CHILD_PINS[3] = {
    {3, 2},
    {4, 5},
    {5, 10},
};
#endif

// ── Components ───────────────────────────────────────────────
WearBlocksCAN        can;
WearBlocksProtocol   protocol;
WearBlocksDescriptor descriptor;
WBModule             module(can, protocol, descriptor);
WBWirelessModule     wireless(module, protocol, descriptor);
MPU6050              imu(Wire);

static const char FW_VERSION[] = "3.0";

uint32_t lastSend = 0;
const uint32_t SEND_INTERVAL = 20;     // 50 Hz

// ── Topic mask ───────────────────────────────────────────────
uint64_t topicMask = 0;
bool isTopicEnabled(uint8_t channelId) { return (topicMask >> channelId) & 1; }

// ── LPF state ────────────────────────────────────────────────
static const float LPF_ALPHA = 0.2f;
float lpf_ax = 0, lpf_ay = 0, lpf_az = 0, lpf_acc_mag = 0;
float lpfUpdate(float& state, float input) {
    state = state + LPF_ALPHA * (input - state);
    return state;
}

// ── Derived / event state ────────────────────────────────────
float prevAccMag = 0;

static const float    SHAKE_THRESHOLD = 3.0f;
static const uint32_t SHAKE_COOLDOWN  = 500;
uint32_t lastShakeTime = 0;

uint16_t stepCount = 0;
bool     stepAboveZero = false;
uint32_t lastStepTime = 0;
static const uint32_t STEP_MIN_INTERVAL = 250;

static const float    FREEFALL_THRESHOLD = 0.3f;
static const uint32_t FREEFALL_DURATION  = 50;
uint32_t freefallStart = 0;
bool     inFreefall = false;

// ── Child-presence debounce ──────────────────────────────────
#if CHILD_DETECT
const uint32_t CHILD_SCAN_TICK         = 20;
const uint8_t  CHILD_DEBOUNCE          = 5;
const uint32_t CHILD_KEEPALIVE_MS      = 2000;
struct ChildTrack { bool committed; uint8_t streak; };
ChildTrack childTracks[3] = {};
uint32_t   lastChildScan = 0;
uint32_t   lastChildBroadcast[3] = {0, 0, 0};

void scanChildren() {
    uint32_t now = millis();
    if (now - lastChildScan < CHILD_SCAN_TICK) return;
    lastChildScan = now;
    static uint8_t cursor = 0;

    bool occ = (digitalRead(CHILD_PINS[cursor].gpio) == LOW);
    ChildTrack& t = childTracks[cursor];
    if (occ == t.committed) {
        t.streak = 0;
    } else {
        t.streak++;
        if (t.streak >= CHILD_DEBOUNCE) {
            t.committed = occ;
            t.streak = 0;
            uint8_t myFaceWhereChildIs = CHILD_PINS[cursor].face;
            Serial.printf("[CHILD] my face %d → %s\n",
                          myFaceWhereChildIs, occ ? "OCCUPIED" : "empty");
            if (module.registered()) {
                protocol.sendChildEvent(myFaceWhereChildIs, occ);
                lastChildBroadcast[cursor] = now;
            }
        }
    }
    cursor = (cursor + 1) % 3;

    // Keepalive: re-broadcast each occupied face every CHILD_KEEPALIVE_MS.
    if (module.registered()) {
        for (uint8_t i = 0; i < 3; i++) {
            if (childTracks[i].committed &&
                now - lastChildBroadcast[i] >= CHILD_KEEPALIVE_MS) {
                protocol.sendChildEvent(CHILD_PINS[i].face, true);
                lastChildBroadcast[i] = now;
            }
        }
    }
}
#endif

// ── Descriptor build ─────────────────────────────────────────
void setupDescriptor() {
    char uid[16];
    snprintf(uid, sizeof(uid), "imu_%08lX", (unsigned long)module.uid());
    strlcpy(descriptor.moduleId, uid, sizeof(descriptor.moduleId));
    strlcpy(descriptor.name, "6-Axis IMU", sizeof(descriptor.name));
    strlcpy(descriptor.category, "motion_sensing", sizeof(descriptor.category));
    strlcpy(descriptor.color, "#7CA1BB", sizeof(descriptor.color));
    strlcpy(descriptor.version, FW_VERSION, sizeof(descriptor.version));

    descriptor.numCapabilities = 2;

    WBCapability& accel = descriptor.capabilities[0];
    strlcpy(accel.type, "sensor", 16);
    strlcpy(accel.modality, "acceleration", 24);
    accel.axes = 3;
    accel.rangeMin = -16.0f;
    accel.rangeMax = 16.0f;
    accel.resolution = 0.001f;
    strlcpy(accel.dataType, "float32[3]", 16);
    accel.sampleRates[0] = 50;
    accel.numSampleRates = 1;

    WBCapability& gyro = descriptor.capabilities[1];
    strlcpy(gyro.type, "sensor", 16);
    strlcpy(gyro.modality, "angular_velocity", 24);
    gyro.axes = 3;
    gyro.rangeMin = -2000.0f;
    gyro.rangeMax = 2000.0f;
    gyro.resolution = 0.1f;
    strlcpy(gyro.dataType, "float32[3]", 16);
    gyro.sampleRates[0] = 50;
    gyro.numSampleRates = 1;

    descriptor.numAffordances = 3;
    strlcpy(descriptor.affordances[0], "detect_gesture", 24);
    strlcpy(descriptor.affordances[1], "track_orientation", 24);
    strlcpy(descriptor.affordances[2], "count_repetitions", 24);

    descriptor.power.voltage = 3.3f;
    descriptor.power.currentTypical = 3.5f;
    descriptor.power.currentPeak = 10.0f;

    descriptor.physical.weight = 4.2f;
    descriptor.physical.dimensions[0] = 15.0f;
    descriptor.physical.dimensions[1] = 15.0f;
    descriptor.physical.dimensions[2] = 5.0f;
    descriptor.physical.numPlacements = 3;
    strlcpy(descriptor.physical.placements[0], "wrist", 16);
    strlcpy(descriptor.physical.placements[1], "forearm", 16);
    strlcpy(descriptor.physical.placements[2], "upper_arm", 16);
}

// ── Topic callback (module-specific) ─────────────────────────
void onTopicChange(uint8_t channelId, bool enable) {
    if (enable) topicMask |= (1ULL << channelId);
    else        topicMask &= ~(1ULL << channelId);
    Serial.printf("[IMU] Topic ch=%d %s\n", channelId, enable ? "ON" : "OFF");
}

void onRegistered(uint8_t slot, bool descriptorCached) {
    Serial.printf("[IMU] Registered slot=%d uid=%08lX cached=%d\n",
                  slot, (unsigned long)module.uid(), descriptorCached);
}
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

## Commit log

2026-05-14 chore: add initial public HexBlocks snapshot
    [hex_module.scad, hex_module.stl, hex_module_h36.scad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]
2026-06-11 docs(readme): tighten overview
2026-06-14 docs(readme): clarify BLE first-run flow
2026-06-16 fix(simulator): use semantic sensor fields
    [hub.ino, serial_bridge.py, test_serial_bridge_sim.py]
2026-06-22 Fix hub hex digit name for Arduino core
    [hub.ino]
2026-08-03 docs: define motor module and motor hub architecture
2026-08-03 docs: design empty topology and motor demo
2026-08-26 feat: add dual motor hub support
2026-08-27 Split wired and Wi-Fi hub firmware targets
